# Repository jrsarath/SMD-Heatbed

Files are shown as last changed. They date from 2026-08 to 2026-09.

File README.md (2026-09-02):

# Tejasvini (तेजस्विनी) — Open-Source Heatplate Controller






**Tejasvini** is an open-source, precision heatplate controller firmware engineered for surface-mount (SMD/SMT) reflow soldering, PCB pre-heating, and rework. It runs on the **Raspberry Pi Pico (RP2040)** paired with an **Elecrow 4.3" Pico DVI Display** running a high-resolution native LVGL user interface with touchscreen and rotary encoder controls.

---

## Key Features

* **Dual NTC Thermistor Sensing**: Redundant 100K 3950 NTC thermistors with 32x oversampling, trimmed-mean outlier rejection, and real-time sensor divergence detection.
* **AC Zero-Cross SSR Drive**: 1000ms time-proportioning slow PWM tailored specifically for AC zero-crossing Solid State Relays (e.g. Fotek SSR-25DA) to avoid half-cycle jitter.
* **Soft-Start Reference Ramping**: Temperature ramps smoothly towards setpoint at $1.5^\circ\text{C}/\text{s}$ to prevent thermal shock to ceramic SMD components and eliminate overshoot.
* **Automated 4-Stage Reflow State Machine**:
  * **Lead-Free (SAC305)**: 245°C peak reflow curve.
  * **Leaded (Sn63Pb37)**: 215°C peak reflow curve.
  * **Low-Temperature (Sn42Bi58)**: 150°C peak reflow curve for heat-sensitive components and plastic connectors.
  * **Manual Mode**: Direct setpoint adjustment (0°C to 270°C).
* **High-Resolution PicoDVI Dashboard**: Renders a 240x400 portrait UI (400x240 hardware DVI upscaled 2x to 800x480) with real-time temperature dials, duty percentage, stage timer, and status.
* **Dual Input Interfaces**: Capacitive touchscreen (GT911) with full on-screen control + detented rotary encoder and debounced push-button.
* **Comprehensive Safety Interlocks**: Fast-trip open/short circuit detection (<100ms), thermal runaway monitoring, 280°C emergency shutdown, pre-heat sensor discrepancy check, and clamped duty cycle (max 40%).
* **Real-Time Telemetry**: Tagged structured telemetry streamed simultaneously over USB CDC Serial and UART `Serial1` (115200 baud).

---

## Hardware Specifications & Bill of Materials (BOM)

| Component | Specification / Recommendation | Purpose |
| :--- | :--- | :--- |
| **Microcontroller** | Raspberry Pi Pico (RP2040, 133MHz, 264KB SRAM, 2MB Flash) | Main controller |
| **Display Module** | Elecrow CrowPanel 4.3" Pico DVI Display (RTD2281 scaler, 800x480 panel) | Native DVI output & touch |
| **Touch Controller**| Goodix GT911 Capacitive Touchscreen (I2C) | On-screen user input |
| **Rotary Encoder** | EC11 detented incremental quadrature encoder with momentary push-button | Manual dial input |
| **Heating Element** | 400W 220V/110V PTC Aluminum Heatplate (e.g. 100mm $\times$ 100mm) | Soldering hot plate |
| **Solid State Relay**| 3.3V Logic-compatible Zero-Cross AC SSR (e.g. Fotek SSR-25DA, 25A 250VAC) | Heater power switching |
| **Temperature Sensors**| $2\times$ 100kΩ NTC Thermistors (Beta = 3950, glass bead cartridge) | Redundant thermal sensing |
| **Divider Resistors**| $2\times$ 100kΩ 1% 1/4W Metal Film Resistors | Precision ADC voltage dividers |
| **Thermal Fuse (TCO)**| Non-resettable thermal cut-off fuse rated at 260°C to 280°C | Physical over-temp safety |
| **Mains Fuse** | 3.15A (for 230V) or 5A (for 110V) fast-acting fuse in IEC inlet socket | Mains over-current safety |

---

## Hardware Pinout Configuration

The firmware assigns GPIO pins in [`src/config.h`](src/config.h) as follows:

```
                                  Raspberry Pi Pico
                                     +---+--+---+
                       (TX) GPIO 0  -| 1    40 |-  VBUS (5V Input)
                       (RX) GPIO 1  -| 2    39 |-  VSYS
              (Encoder A)   GPIO 2  -| 4    38 |-  GND
              (Encoder B)   GPIO 3  -| 5    37 |-  3V3_EN
                            ...     -| ...  36 |-  3V3(OUT)
              (Touch SDA)   GPIO 20 -| 26   34 |-  GPIO 28 (Encoder Button)
              (Touch SCL)   GPIO 21 -| 27   32 |-  GPIO 27 (ADC1 / NTC2)
              (SSR Drive)   GPIO 22 -| 29   31 |-  GPIO 26 (ADC0 / NTC1)
              (Backlight)   GPIO 24 -| 30   30 |-  RUN
              (Touch INT)   GPIO 25 -| 31   29 |-  GPIO 29 (Touch RST)
                                     +----------+
```

| Signal | GPIO Pin | Hardware Function | Notes |
| :--- | :--- | :--- | :--- |
| `PIN_ENA` | GPIO 2 | Rotary Encoder Phase A | Internal pullup enabled |
| `PIN_ENB` | GPIO 3 | Rotary Encoder Phase B | Internal pullup enabled |
| `PIN_EBT` | GPIO 28 | Rotary Encoder Push-Button | Internal pullup enabled (Active LOW) |
| `PIN_SSR` | GPIO 22 | Solid State Relay Output | 3.3V logic time-proportioning drive |
| `PIN_NTC1` | GPIO 26 | Primary NTC Thermistor | RP2040 ADC0 (12-bit), 100kΩ divider |
| `PIN_NTC2` | GPIO 27 | Secondary NTC Thermistor | RP2040 ADC1 (12-bit), 100kΩ divider |
| `PIN_BACKLIGHT` | GPIO 24 | Display Backlight Enable | Active LOW |
| `TOUCH_SDA` | GPIO 20 | GT911 I2C Data | 4.7kΩ pullups required |
| `TOUCH_SCL` | GPIO 21 | GT911 I2C Clock | 4.7kΩ pullups required |
| `TOUCH_INT` | GPIO 25 | GT911 Touch Interrupt | Configured in `src/touch.h` |
| `TOUCH_RST` | GPIO 29 | GT911 Touch Reset | Configured in `src/touch.h` |
| `SERIAL_TX` | GPIO 0 | Telemetry UART TX (`Serial1`) | 115200 baud |
| `SERIAL_RX` | GPIO 1 | Telemetry UART RX (`Serial1`) | 115200 baud |

---

## Enclosure & 3D Hardware Models

Tejasvini includes CAD & 3D models in [`assets/3d files/`](assets/3d%20files/) for building a complete desktop workstation enclosure:

### 3D Printable Enclosure Parts
| Model File | Part Description | Recommended Material | Print Settings |
| :--- | :--- | :--- | :--- |
| [`Frame - Main.stl`](assets/3d%20files/Frame%20-%20Main.stl) | Main chassis housing RP2040, SSR, power supply & wiring | PETG / ABS / ASA | 35% Infill, 4 walls |
| [`Frame - Display.stl`](assets/3d%20files/Frame%20-%20Display.stl) | Front bezel securing the 4.3" Pico DVI display & GT911 touch | PETG / ABS / PLA | 25% Infill, 3 walls |
| [`Display Bottom Plate.stl`](assets/3d%20files/Display%20Bottom%20Plate.stl) | Rear protective backing plate for the display module | PETG / ABS / PLA | 25% Infill, 3 walls |
| [`Top Plate.stl`](assets/3d%20files/Top%20Plate.stl) | Top deck plate surrounding the heatplate surface | **ABS / ASA / PC** *(High HDT)* | 40% Infill, 4 walls |

### Physical Hardware Reference (Do NOT 3D Print)
| Model File | Part Description | Material | Notes |
| :--- | :--- | :--- | :--- |
| [`Heating Plate.stl`](assets/3d%20files/Heating%20Plate.stl) | **Heatplate CAD Reference** | **Aluminium** | **Visualization & fit checks only.** Must be fabricated from aluminum (sheet / CNC machined block). Do **not** 3D print this part. |

> [!IMPORTANT]
> **Thermal Standoffs & Material Selection**:
> * **Heating Plate Material**: The heating surface (`Heating Plate.stl`) MUST be made of **aluminium** to conduct heat and withstand reflow temperatures up to 250°C.
> * **Enclosure Plastic**: For printed components near the heatplate (`Top Plate.stl`), use materials with a high Heat Deflection Temperature (HDT) such as **ABS, ASA, or Polycarbonate (PC)**. Standard PLA softens around 55°C–60°C and must **not** be used near the heater. Always install silicone washers, ceramic washers, or brass/PTFE standoffs to thermally isolate the 200°C+ aluminum plate from printed enclosure surfaces.

---

## Safety Architecture & Physical Protections

> [!CAUTION]
> **Mains Voltage & Thermal Fire Warning**:
> Heating elements can exceed 280°C and cause severe burns, fire, or toxic gas generation. Solid-state relays almost always fail in a **shorted (ON)** state.
>
> You MUST install independent physical hardware protections:
> 1. **Thermal Cut-Off Fuse (TCO)**: A physical bimetallic or chemical thermal fuse rated at 260°C–280°C MUST be clamped directly against the aluminum plate in series with the AC Live wire.
> 2. **Chassis Earth Grounding**: The metal heatplate MUST be bonded to the AC mains protective earth wire (<0.1Ω to plug ground pin).
> 3. **Mains Fuse**: Fast-acting fuse sized for plate wattage.
>
> See [docs/hardware_and_safety.md](docs/hardware_and_safety.md) for full schematics and electrical requirements.

### Firmware Multi-Tier Safety Checks
* **Instant Open/Short Detection (<100ms)**: Raw ADC counts outside 50 to 4050 counts or raw temperatures outside -20°C to 300°C trip an immediate emergency shutdown.
* **Thermal Runaway Monitor**: Detects disconnected sensors or insufficient temperature rise under active heating within 18 seconds (`SAFETY_PERIOD`).
* **Sensor Divergence Lockout**: Detects detached sensors or uneven plate heating if the dual thermistors disagree by $> 35^\circ\text{C}$ during heating, or $> 15^\circ\text{C}$ before startup.
* **Duty Cycle Clamping**: SSR output is hard-clamped to 40% (`MAX_DUTY`) to protect the heating element and SSR.
* **Latching Shutdown (`trigger_safety_shutdown`)**: All safety trips immediately force the SSR GPIO LOW and require explicit user intervention to clear.

---

## Firmware Software Architecture

The firmware is structured into modular components operating cooperatively:

```text
Tejasvini/
├── Tejasvini.ino             # Main Arduino sketch (setup & cooperative non-blocking loop)
├── CMakeLists.txt            # CMake build definition
├── LICENSE                   # MIT License
├── README.md                 # Project documentation (this file)
├── CONTRIBUTING.md           # Developer guidelines & safety standards
├── CODE_OF_CONDUCT.md        # Contributor Covenant Code of Conduct
├── assets/
│   └── 3d files/             # Ready-to-print STL enclosure & mounting models
├── docs/
│   ├── architecture.md       # Detailed software architecture & state machines
│   ├── hardware_and_safety.md# Pinout, NTC voltage divider math, SSR & safety fuses
│   └── calibration_and_tuning.md # PI loop tuning & sensor calibration
└── src/
    ├── config.h              # Hardware pinout, thermal constants & safety parameters
    ├── display_manager.h/.cpp# PicoDVI display driver, LVGL bridge, reflow state machine
    ├── input_handler.h/.cpp  # Rotary encoder decoding & button debouncing
    ├── telemetry.h/.cpp      # USB CDC & UART serial logging
    ├── thermal_control.h/.cpp# Dual NTC ADC acquisition, PI regulator, SSR PWM, safety
    ├── touch.h/.cpp          # Touchscreen driver abstraction (GT911)
    └── ui/                   # EEZ Studio generated LVGL UI screens, styles, and vars
```

---

## Building and Flashing the Firmware

### Option 1: Using `arduino-cli` (Recommended)

1. Install the [Earle F. Philhower RP2040 Core](https://github.com/earlephilhower/arduino-pico).
2. Install required Arduino libraries (`PicoDVI`, `Adafruit_GFX`, `Adafruit_BusIO`, `lvgl`, `RP2040_PWM`, `RPI_PICO_TimerInterrupt`, `TAMC_GT911`).
3. Compile the project:
   ```bash
   arduino-cli compile \
     -b rp2040:rp2040:rpipico \
     --build-property "build.extra_flags=-DLV_LVGL_H_INCLUDE_SIMPLE -DLV_USE_OBJ_NAME=1 -DLV_USE_TRANSLATION=1 -Wall -Wextra" \
     .
   ```
4. Flash to the board:
   ```bash
   arduino-cli upload -p /dev/tty.usbmodem* -b rp2040:rp2040:rpipico .
   ```
   *(Or hold the **BOOTSEL** button on the Pico while plugging in USB, then copy the compiled `.uf2` file to the `RPI-RP2` drive).*

### Option 2: Using the Arduino IDE 2.x

1. Open `Tejasvini.ino` in Arduino IDE.
2. Select **Board:** `Raspberry Pi Pico` (under Raspberry Pi RP2040 by Earle Philhower).
3. Under **Tools**, configure:
   * **CPU Speed:** 133 MHz (or 200 MHz)
   * **Flash Size:** 2MB (Sketch: 1984KB, FS: 64KB)
   * **USB Stack:** Adafruit TinyUSB
4. Click **Verify** (`Ctrl+R` / `Cmd+R`) and **Upload** (`Ctrl+U` / `Cmd+U`).

---

## Operating Instructions

1. **Boot Screen**: Displays the project banner, firmware version, and initializes the DVI dashboard.
2. **Temperature Adjustment**:
   * Rotate the rotary encoder dial to increase/decrease target temperature in 1°C steps.
   * Or tap the on-screen temperature arc/buttons to adjust setpoint.
3. **Toggle Heating**:
   * Short-press the encoder knob or tap the **START HEATING** button on the display.
4. **Reflow Profile Selection**:
   * Tap the profile dropdown on the dashboard to select **MANUAL**, **LEAD FREE**, **LEADED**, or **LOW TEMP**.
   * Progress bar indicates current stage progress (0–25% Preheat, 25–50% Soak, 50–75% Reflow Peak, 75–100% Cool).
5. **Clear Error / Reset Fault**:
   * Long-press the encoder knob (>1.0 second) to attempt clearing an error state once sensor readings return to valid bounds.

---

## Telemetry Stream

Tejasvini streams structured status logs every 1000ms over USB Serial and UART `Serial1` (GPIO 0 TX / GPIO 1 RX @ 115200 baud):

```text
[Telemetry] Temp: 149.8C (T1: 150.1, T2: 149.5, dT: 0.6) | Target: 150C (Ref: 150.0) | Duty: 24.5% | Status: SOAK [LEAD FREE] | ADC: [2480/98.4k, 2475/98.1k] | Heap: 87450B
```

Send `b` or `?` over the serial monitor to reprint the diagnostic boot banner.

---

## Documentation

* [Architecture & State Machines](docs/architecture.md)
* [Hardware Wiring, Schematics & Safety Fuses](docs/hardware_and_safety.md)
* [Calibration & Controller Tuning](docs/calibration_and_tuning.md)

---

## Contributing

Contributions are welcome! Please read [CONTRIBUTING.md](CONTRIBUTING.md) and our [Code of Conduct](CODE_OF_CONDUCT.md) before submitting pull requests.

---

## License

This project is open-source under the **MIT License**. See the [LICENSE](LICENSE) file for details.

Copyright (c) 2026 Sarath "Delta" Singh <br />
Made with ❤️ in Kolkata, India.

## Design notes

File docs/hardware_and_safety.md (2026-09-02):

# Hardware Wiring & Physical Safety Guide

This document outlines the electrical connections, sensor circuits, solid-state relay considerations, and mandatory physical safety mechanisms required for building and operating **Tejasvini**.

---

## 1. Safety Warnings & Physical Protections

> [!CAUTION]
> **DANGER: MAINS VOLTAGE AND HIGH TEMPERATURE HAZARDS**
> * Tejasvini controls **mains AC voltage** (110V / 230V AC) and heating elements capable of reaching **exceeding 280°C**.
> * Mains electricity can cause fatal electric shock. High temperatures cause severe burns and fire.
> * **Software is NOT a safety mechanism.** Solid-state relays fail in a short-circuit (ON) state in roughly 90% of failure modes. If a microcontroller crashes or an SSR semiconductor fails shorted, firmware cannot shut off power.
> * You MUST incorporate the physical hardware protections described below.

### Mandatory Physical Protections
1. **Thermal Cut-Off Fuse (TCO / Thermal Fuse)**:
   - Install a non-resettable thermal fuse (rated at **260°C to 280°C**) clamped directly to the underside of the aluminum heatplate in physical contact with the metal.
   - Wire the thermal fuse in **series** with the AC Live line feeding the heating element. If the plate overheats for any reason, the fuse physically melts and permanently breaks the circuit.
2. **Protective Earth (PE) Grounding**:
   - The aluminum heatplate and all exposed metal chassis parts MUST be securely bonded to the AC mains Earth wire with a dedicated screw, lock washer, and ring terminal.
   - Use a multimeter to verify $< 0.1\,\Omega$ resistance between the heatplate surface and the ground pin of the mains plug.
3. **Mains Over-Current Fuse**:
   - Install a properly rated fast-blow fuse in a fused AC inlet socket (e.g., 3.15A for 230V 400W plate, or 5A for 110V 400W plate).
4. **Solid-State Relay (SSR) Heatsinking**:
   - Solid-state relays exhibit an internal forward voltage drop of $\approx 1.2\,\text{V}$ to $1.6\,\text{V}$. At a 2A load, this dissipates $2.5\,\text{W}$ to $3.5\,\text{W}$ of heat inside the SSR.
   - Mount the SSR to a metal chassis or aluminum heatsink using thermal paste. Never operate the SSR in a sealed unventilated plastic enclosure.

---

## 2. Hardware Pinout Table

| Signal | RP2040 GPIO Pin | Hardware Header / Function | Notes |
| :--- | :--- | :--- | :--- |
| `PIN_ENA` | GPIO 2 | Rotary Encoder Phase A | Internal `INPUT_PULLUP` enabled |
| `PIN_ENB` | GPIO 3 | Rotary Encoder Phase B | Internal `INPUT_PULLUP` enabled |
| `PIN_EBT` | GPIO 28 | Rotary Encoder Push-Button | Internal `INPUT_PULLUP` enabled (Active LOW) |
| `PIN_SSR` | GPIO 22 | Solid State Relay Output | 3.3V Logic Drive (Time-Proportioning) |
| `PIN_NTC1` | GPIO 26 | Primary Thermistor (ADC0) | 12-bit ADC, 100kΩ divider to GND |
| `PIN_NTC2` | GPIO 27 | Secondary Thermistor (ADC1) | 12-bit ADC, 100kΩ divider to GND |
| `PIN_BACKLIGHT`| GPIO 24 | Display Backlight Control | Active LOW (driven LOW to illuminate) |
| `TOUCH_SDA` | GPIO 20 | GT911 Touch Controller I2C SDA | Requires 4.7kΩ pullups to 3.3V |
| `TOUCH_SCL` | GPIO 21 | GT911 Touch Controller I2C SCL | Requires 4.7kΩ pullups to 3.3V |
| `TOUCH_INT` | GPIO 25 | GT911 Touch Controller Interrupt | Configured in `src/touch.h` |
| `TOUCH_RST` | GPIO 29 | GT911 Touch Controller Reset | Configured in `src/touch.h` |
| `SERIAL_TX` | GPIO 0 | Telemetry UART TX (`Serial1`) | 115200 baud, 8N1 |
| `SERIAL_RX` | GPIO 1 | Telemetry UART RX (`Serial1`) | 115200 baud, 8N1 |

---

## 3. Dual NTC Thermistor Circuit & Math

Tejasvini uses **dual 100K 3950 NTC thermistors** mounted at separate positions across the heating surface (e.g. center and edge) to provide redundancy and detect thermal gradients or detached sensors.

### 3.1 Voltage Divider Circuit
Each thermistor is wired in a high-side divider configuration:

```text
       3.3V (VCC)
         │
       ┌─┴─┐
       │   │  NTC Thermistor (100kΩ @ 25°C)
       │   │  R_NTC
       └─┬─┘
         ├──────────────> RP2040 ADC Pin (GPIO 26 or GPIO 27)
       ┌─┴─┐
       │   │  Precision Divider Resistor (100kΩ, 1% tolerance)
       │   │  R_DIVIDER
       └─┬─┘
         │
        GND
```

### 3.2 Mathematical Derivation
The voltage at the ADC input pin is:
$$V_{\text{out}} = V_{\text{cc}} \cdot \frac{R_{\text{divider}}}{R_{\text{ntc}} + R_{\text{divider}}}$$

With a 12-bit ADC full-scale count of $4095$ corresponding to $V_{\text{cc}}$:
$$\frac{\text{ADC}}{4095} = \frac{R_{\text{divider}}}{R_{\text{ntc}} + R_{\text{divider}}}$$

Inverting both sides:
$$\frac{4095}{\text{ADC}} = \frac{R_{\text{ntc}}}{R_{\text{divider}}} + 1 \implies R_{\text{ntc}} = R_{\text{divider}} \cdot \left(\frac{4095}{\text{ADC}} - 1\right)$$

### 3.3 Steinhart-Hart / Beta Temperature Conversion
From the calculated resistance $R_{\text{ntc}}$, temperature in Kelvin is determined via the Beta equation:
$$\frac{1}{T} = \frac{1}{T_0} + \frac{1}{\beta} \cdot \ln\left(\frac{R_{\text{ntc}}}{R_0}\right)$$

Where:
* $T_0 = 298.15\,\text{K}$ ($25^\circ\text{C}$)
* $R_0 = 100{,}000\,\Omega$ ($100\text{k}\Omega$)
* $\beta = 3950\,\text{K}$
* $T_{\text{Celsius}} = T_{\text{Kelvin}} - 273.15$

### 3.4 Electrical Fault Signatures
* **Broken / Disconnected NTC (Open Circuit)**: $R_{\text{ntc}} \to \infty$. The ADC pin is pulled to GND by $R_{\text{divider}}$, reading $\text{ADC} \approx 0$ counts.
* **Shorted NTC (Short to 3.3V)**: $R_{\text{ntc}} \to 0$. The ADC pin is pulled directly to 3.3V, reading $\text{ADC} \approx 4095$ counts.
* **Firmware Fast Bounds**: Tejasvini checks $\text{ADC} < 50$ or $\text{ADC} > 4050$ counts and shuts off immediately ($<100\text{ms}$).

---

## 4. Solid-State Relay (SSR) Wiring

### 4.1 AC Mains SSR Connection
Connect a 3.3V-logic compatible AC Zero-Cross Solid State Relay (e.g. Fotek SSR-25DA or Crydom D2425):

```text
[Raspberry Pi Pico]                      [AC Mains Solid-State Relay]
GPIO 22 ───────────────────────────────> Input (+) [Terminal 3]
GND     ───────────────────────────────> Input (-) [Terminal 4]

[AC Mains 230V/110V Live] ────[Mains Fuse]───[Thermal Cutoff 260°C]───> Output [Terminal 1]
                                                                        Output [Terminal 2] ───> [PTC Heatplate L]
[AC Mains Neutral] ────────────────────────────────────────────────────────────────────────────> [PTC Heatplate N]
[AC Mains Earth]   ────────────────────────────────────────────────────────────────────────────> [Heatplate Metal Body]
```

### 4.2 Why Time-Proportioning is Used Instead of High-Frequency PWM
Zero-crossing AC solid-state relays only switch on and off when the AC line voltage passes through 0V (every 10ms at 50Hz, or 8.33ms at 60Hz).
* Applying a 1000 Hz PWM signal to an AC zero-cross SSR results in random, irregular half-cycle conduction, extreme flicker, and unpredictable power delivery.
* Tejasvini uses **Time-Proportioning PWM** over a 1000ms window (`SSR_WINDOW_MS 1000`). At 25% duty, the relay conducts for 250ms (12.5 complete AC cycles at 50Hz) and remains OFF for 750ms.

---

## 5. Mechanical Enclosure & 3D Hardware Models

CAD & 3D models for Tejasvini are located in [`assets/3d files/`](../assets/3d%20files/).

### 5.1 3D Model Manifest

#### 3D Printable Parts
| File Name | Functional Description | Print Recommendation |
| :--- | :--- | :--- |
| [`Frame - Main.stl`](../assets/3d%20files/Frame%20-%20Main.stl) | Main structural chassis. Houses the Raspberry Pi Pico, solid-state relay, AC terminal block, and power distribution. | PETG / ABS / ASA, 35% infill, 4 perimeters |
| [`Frame - Display.stl`](../assets/3d%20files/Frame%20-%20Display.stl) | Angled front display bezel. Secures the Elecrow 4.3" CrowPanel RTD2281 DVI screen and GT911 touch panel. | PETG / ABS / PLA, 25% infill, 3 perimeters |
| [`Display Bottom Plate.stl`](../assets/3d%20files/Display%20Bottom%20Plate.stl) | Rear/bottom cover plate for the display module housing, protecting display PCB and encoder wiring. | PETG / ABS / PLA, 25% infill, 3 perimeters |
| [`Top Plate.stl`](../assets/3d%20files/Top%20Plate.stl) | Top cosmetic deck plate surrounding the heating zone, providing a smooth, flush exterior interface. | **ABS / ASA / PC**, 40% infill, 4 perimeters |

#### Physical Hardware Reference (Do NOT 3D Print)
| File Name | Functional Description | Material | Notes |
| :--- | :--- | :--- | :--- |
| [`Heating Plate.stl`](../assets/3d%20files/Heating%20Plate.stl) | Physical heating plate reference model. | **Aluminium** | **Visualization only.** Must be fabricated from aluminum (sheet / CNC machined plate). Never 3D print. |

### 5.2 Assembly & Thermal Isolation
Because the aluminum heatplate operates at temperatures up to 250°C, direct contact between the metal plate and thermoplastic components will cause warping or melting:

1. **Aluminium Plate Construction**:
   - The actual heating surface represented by `Heating Plate.stl` **must be made of aluminum** for optimal thermal conductivity and heat distribution across the PCB work area.
2. **Thermal Standoffs**:
   - Mount the aluminum heating plate to the chassis using M3 brass standoffs (minimum 10mm to 15mm height) to establish a convective air gap above the electronics.
   - Place heat-resistant silicone grommets or ceramic washers between the screw heads and the plate mounting holes to prevent conductive heat transfer into the printed `Top Plate.stl` or chassis.
3. **Thermal Fuse Mounting**:
   - The 260°C–280°C thermal cut-off fuse (TCO) should be mounted directly to the underside of the aluminum heatplate with a metal retaining clip or high-temperature silicone adhesive, ensuring intimate thermal contact.
4. **Internal Airflow**:
   - The main frame features ventilation slots to promote natural convection around the SSR heatsink and the Raspberry Pi Pico.

### 5.3 Filament Material Guide

| Filament Material | Glass Transition ($T_g$) | Heat Deflection (HDT @ 0.45MPa) | Suitability for Tejasvini |
| :--- | :--- | :--- | :--- |
| **PLA** | ~55°C – 60°C | ~55°C | **Only for Display Bezel**. Never use near the heater plate. |
| **PETG** | ~80°C – 85°C | ~70°C – 75°C | Excellent for Main Frame & Display housing. |
| **ABS / ASA** | ~105°C | ~95°C – 100°C | **Recommended** for Heating Plate mount and Top Plate. |
| **PC (Polycarbonate)** | ~145°C – 150°C | ~135°C – 140°C | **Best performance** for high-temperature continuous operation. |

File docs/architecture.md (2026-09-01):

# Tejasvini Firmware Architecture

This document provides a comprehensive technical overview of the software architecture, subsystem interactions, control loops, and memory organization of the **Tejasvini** heatplate controller firmware.

---

## 1. System Overview & Execution Model

Tejasvini runs on a **Raspberry Pi Pico (RP2040)** with dual ARM Cortex-M0+ cores. The current firmware executes on **Core 0** in a cooperative, non-blocking polling model inside `loop()`, ensuring predictable timing, low latency, and deterministic memory behavior without complex inter-core synchronization.

```mermaid
graph TD
    A[Tejasvini.ino loop] --> B[input_handler_update]
    A --> C[thermal_control_update]
    A --> D[display_manager_update]
    A --> E[telemetry_update]
    A --> F[yield]

    B --> B1[Rotary Encoder Quadrature Decoding]
    B --> B2[Button Debounce Short/Long Press]

    C --> C1[read_oversampled_adc 32x Trimmed]
    C --> C2[Raw ADC & Temp Bounds Check]
    C --> C3[EMA Low-Pass & Slew Limiter]
    C --> C4[PI Controller & Soft-Start Ramp]
    C --> C5[update_ssr_actuation Time-Proportioning]
    C --> C6[Thermal Runaway & Divergence Checks]

    D --> D1[update_profile_and_progress State Machine]
    D --> D2[ui_tick EEZ Studio]
    D --> D3[lv_timer_handler LVGL Renderer]
    D --> D4[dvi_flush_cb PicoDVI Draw]

    E --> E1[Serial USB CDC & Serial1 UART 115200]
```

### Main Execution Loop Breakdown
| Function | Frequency / Interval | Purpose |
| :--- | :--- | :--- |
| `input_handler_update()` | Continuous (~100-200 Hz) | Instant quadrature edge detection and button debouncing |
| `thermal_control_update()` | SSR: Continuous<br>PI Loop: 10 Hz (100 ms) | Time-proportioning SSR actuation and 100ms PI temperature regulation |
| `display_manager_update()` | Continuous (~30-60 Hz) | LVGL tick handling, UI animations, reflow state transitions, DVI flush |
| `telemetry_update()` | 1 Hz (1000 ms) | Formatted telemetry output over USB Serial and Hardware UART |

---

## 2. Thermal Control & Safety Subsystem (`src/thermal_control`)

### 2.1 Sensor Acquisition Pipeline
Dual 100K NTC thermistors (`PIN_NTC1` on ADC0/GPIO 26, `PIN_NTC2` on ADC1/GPIO 27) are read through a 3-tier filtering pipeline:

1. **32x Oversampling with Outlier Rejection (`read_oversampled_adc`)**:
   - 32 analog samples acquired with 4µs settling delays.
   - Sorted in-place using an insertion sort on a small stack buffer.
   - The 6 highest and 6 lowest readings are discarded (trimmed mean).
   - The 20 middle samples are averaged, eliminating power rail switching spikes, DVI noise, and ADC glitch pulses.
2. **Fast Raw ADC & Electrical Bounds Check**:
   - Raw ADC values must lie strictly between `ADC_MIN_VALID_COUNTS` (50) and `ADC_MAX_VALID_COUNTS` (4050).
   - Raw temperatures must lie strictly between `NTC_MIN_VALID_TEMP` (-20°C) and `NTC_MAX_VALID_TEMP` (300°C).
   - If either sensor violates these bounds (broken wire, loose plug, or dead short), `trigger_safety_shutdown()` trips **immediately** ($< 100\text{ms}$) without passing the corrupt value to the smoothing filter.
3. **EMA Low-Pass Filter + Physical Slew Limiter**:
   - Exponential Moving Average ($\alpha = 0.08$) smooths sensor noise.
   - A physical slew limiter clamps the maximum allowable temperature change to `0.25°C` per 100ms step (equivalent to $2.5^\circ\text{C}/\text{s}$ max rise/fall).

### 2.2 PI Regulation & Soft-Start Ramping
* **Soft-Start Ramping**: Rather than stepping the PI setpoint directly to the target temperature, `reference_temp` ramps towards `set_temp` at a rate of `RAMP_RATE_DEG_PER_SEC` ($1.5^\circ\text{C}/\text{s}$). This prevents severe thermal shock to delicate ceramic SMD components and reduces heater overshoot.
* **PI Controller**:
  $$e(t) = T_{\text{ref}}(t) - T_{\text{measured}}(t)$$
  $$u(t) = K_p \cdot e(t) + K_i \cdot \int e(t)\,dt$$
  - $K_p = 1.5$, $K_i = 0.02$.
  - Integration accumulator is time-scaled ($dt$ integration) and includes **anti-windup clamping**: accumulator growth is frozen when the output saturates at `MAX_DUTY` (40%) or `MIN_DUTY` (0%).

### 2.3 SSR Actuation: Time Proportioning
Because AC Solid State Relays (such as the Fotek SSR-25DA) switch on AC zero-crossings (every 10ms for 50Hz or 8.33ms for 60Hz), standard high-frequency PWM cannot be used.
Tejasvini uses **Time-Proportioning Slow PWM** (`SSR_TIME_PROPORTIONING 1`):
* A 1000ms cycle window (`SSR_WINDOW_MS 1000`) is established.
* At 40% duty, the SSR pin is driven HIGH for 400ms and LOW for 600ms.
* `update_ssr_actuation()` is evaluated continuously on every loop pass for sub-millisecond switching accuracy.

### 2.4 Multi-Layered Safety Interlocks
1. **Emergency Over-Temperature Shutdown**: If composite or individual sensor temperature exceeds `OVERTEMP_SHUTDOWN` (280°C), the SSR is instantly killed and locked out.
2. **Sensor Divergence Lockout**:
   - **Pre-Heat**: Both sensors must agree within `MAX_STARTUP_NTC_DIFF` (15°C) before heating is permitted to start.
   - **Active Heating**: If sensors diverge by $> 35^\circ\text{C}$ (`MAX_NTC_DIFF`) for 5 consecutive cycles (500ms debounce), the heater is shut down.
3. **Thermal Runaway Monitor**:
   - When driving $\ge 20\%$ duty with a deficit $> 10^\circ\text{C}$, temperature must rise by at least `SAFETY_THRESHOLD` (2.0°C) within `SAFETY_PERIOD` (18 seconds).
   - Hysteresis prevents timer starvation under fluctuating power.
4. **Centralized Fail-Safe Shutdown (`trigger_safety_shutdown`)**:
   - Latches `error_state = true`.
   - Forces `heater = false`, `duty = 0.0f`, `acc = 0.0f`.
   - Directly writes `PIN_SSR` LOW.
   - Requires explicit user interaction to reset.

---

## 3. Display & UI Subsystem (`src/display_manager` & `src/ui`)

### 3.1 Display Pipeline (PicoDVI & LVGL 8.3.x)
* **Hardware Output**: PicoDVI generates a 400x240 RGB565 DVI signal at 60Hz. The Elecrow CrowPanel RTD2281 scaler board upscales this 2x to fill the 800x480 native LCD panel.
* **Rotation**: The display is rotated 270° (`setRotation(3)`), presenting a logical **240x400 Portrait** UI to LVGL.
* **Partial Buffer Strategy**: LVGL renders into an 8-line partial buffer (`240 * 8 * 2 = 3840 bytes`), consuming negligible SRAM while providing artifact-free rendering.
* **Touch Controller**: Bridges GT911 capacitive touch over I2C (GPIO 20 SDA, GPIO 21 SCL), converting touch coordinates to 240x400 portrait space.

### 3.2 Reflow Profile State Machine
`display_manager.cpp` manages an automated 4-stage reflow state machine:

```mermaid
stateDiagram-v2
    [*] --> STAGE_IDLE
    STAGE_IDLE --> STAGE_PREHEAT : Start Heating (Profile != MANUAL)
    STAGE_IDLE --> MANUAL_HEATING : Start Heating (Profile == MANUAL)

    STAGE_PREHEAT --> STAGE_SOAK : Reached preheat_temp
    STAGE_SOAK --> STAGE_REFLOW : soak_time_s elapsed
    STAGE_REFLOW --> STAGE_COOL : peak_dwell_s elapsed (Heater OFF)
    STAGE_COOL --> STAGE_IDLE : Cooled <= cool_temp (50°C)

    STAGE_PREHEAT --> STAGE_IDLE : User Abort / Error
    STAGE_SOAK --> STAGE_IDLE : User Abort / Error
    STAGE_REFLOW --> STAGE_IDLE : User Abort / Error
    STAGE_COOL --> STAGE_IDLE : User Cancel
    MANUAL_HEATING --> STAGE_IDLE : Stop Heating / Error
```

Supported profiles:
1. **MANUAL**: Direct setpoint control (0 - 270°C).
2. **LEAD FREE (SAC305)**: Preheat 150°C (90s) $\to$ Soak 175°C (60s) $\to$ Peak Reflow 245°C (30s dwell) $\to$ Cool to 50°C.
3. **LEADED (Sn63Pb37)**: Preheat 130°C (80s) $\to$ Soak 155°C (60s) $\to$ Peak Reflow 215°C (30s dwell) $\to$ Cool to 50°C.
4. **LOW TEMP (Sn42Bi58)**: Preheat 90°C (60s) $\to$ Soak 115°C (45s) $\to$ Peak Reflow 150°C (25s dwell) $\to$ Cool to 45°C.

---

## 4. Memory Footprint & Resource Budget

The RP2040 features 264 KB on-chip SRAM:

| Memory Region | Allocation | Notes |
| :--- | :--- | :--- |
| **PicoDVI Framebuffer** | ~153.6 KB | Contiguously allocated in dynamic heap by `DVIGFX16` |
| **Static Data (.data + .bss)** | ~20.2 KB | Global state, buffers, LVGL static tables |
| **LVGL Draw Buffer** | 3.84 KB | 8 lines $\times$ 240 pixels $\times$ 2 bytes (RGB565) |
| **Remaining Free Heap & Stack**| >85 KB | Available for LVGL dynamic objects and call stack |
| **Flash Usage** | ~366 KB / 2 MB (17%)| Ample space for additional profiles, fonts, and assets |

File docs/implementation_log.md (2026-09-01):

# SMD-Heatbed Display Manager & LVGL Integration Log

This document serves as a persistent step-by-step implementation log to track code changes, hardware diagnostic results, memory benchmarks, state analysis, and rollback checkpoints for the PicoDVI display driver & LVGL Pro UI integration on RP2040.

---

## Current System State Analysis (Checkpoint 0)
- **Hardware Target:** Raspberry Pi Pico (RP2040) + Elecrow 4.3" Pico DVI Display (320x240 RGB565).
- **Display Hardware Driver:** `DVIGFX16 display(DVI_RES_320x240p60, picodvi_dvi_cfg)` via Adafruit PicoDVI library.
- **Current Codebase State:**
  - `src/display_manager.h` & `src/display_manager.cpp`: Bare minimum hardware driver setup with a 1-second RGB color cycle (Red -> Green -> Blue).
  - `src/config.h`: Configured with LVGL heap optimization flags (`LV_MEM_CUSTOM 1`, `LV_USE_STDLIB_MALLOC 1`, `LV_MEM_SIZE (32 * 1024U)`).
  - `SMD-Heatbed.ino`: Calls `display_manager_init()` in `setup()` and `display_manager_update()` in `loop()`.
- **Key Technical Findings:**
  - **Memory Baseline:** RP2040 SRAM is 264 KB. PicoDVI requires a 153.6 KB (153,600 bytes) contiguous dynamic allocation for the 320x240 16-bit DVI framebuffer.
  - **Prior Blocker Solved:** Default LVGL static memory pool pre-allocated ~192 KB in `.bss`, leaving only ~10 KB free heap and causing `display.begin()` to hang. Configuring dynamic heap for LVGL expanded available heap to >20 KB before DVI init and allowed `display.begin()` to report `SUCCESS`.

---

## Log Trajectory & History

### Entry #001 — Bare Minimum RGB Flashing Test
- **Date & Time:** 2026-08-25 01:23:16 IST
- **Goal:** Verify raw hardware DVI signal generation, GPIO backlight control, and DVI framebuffer writing independently of LVGL rendering pipeline.
- **Files Modified:**
  - [`src/display_manager.h`](file:///Users/jrsarath/Documents/GitHub/SMD-Heatbed/src/display_manager.h)
  - [`src/display_manager.cpp`](file:///Users/jrsarath/Documents/GitHub/SMD-Heatbed/src/display_manager.cpp)
- **Code State Details:**
  - Backlight pin `PIN_BACKLIGHT` (GPIO 24) set `OUTPUT` & `LOW`.
  - `display.begin()` called and result logged over `Serial1`.
  - `display_manager_update()` implements a 1000ms timer switching between `COLOR_RED` (`0xF800`), `COLOR_GREEN` (`0x07E0`), and `COLOR_BLUE` (`0x001F`).
- **Telemetry Log Output:**
  ```text
  [Display] Initializing backlight & PicoDVI hardware...
  [Display] Free Heap before DVI init: 20272 bytes
  [Display] Calling display.begin()...
  [Display] display.begin() result: SUCCESS
  [Display Pattern] Initial Fill: RED
  [Display Pattern] GREEN
  [Display Pattern] BLUE
  ```
- **Checkpoint Status:** BASELINE CHECKPOINT #0 CONFIRMED WORKING.

---

### Entry #002 — Integrated LVGL Pro UI Driver & Home Screen
- **Date & Time:** 2026-08-25 01:24:12 IST
- **Goal:** Re-integrate the declarative LVGL Pro UI library (`src/lvgl_ui`) onto the confirmed working PicoDVI hardware display foundation.
- **Files Modified:**
  - [`src/display_manager.h`](file:///Users/jrsarath/Documents/GitHub/SMD-Heatbed/src/display_manager.h)
  - [`src/display_manager.cpp`](file:///Users/jrsarath/Documents/GitHub/SMD-Heatbed/src/display_manager.cpp)
- **Code State Details:**
  - `lv_init()` & `lv_tick_set_cb(my_tick_cb)` initialized for hardware millisecond timing.
  - `lv_display_create(320, 240)` created with `LV_COLOR_FORMAT_RGB565` and 8-line partial buffer (`lvgl_buf`).
  - High-performance zero-copy `memcpy` row flushing to `display.getBuffer()` in `dvi_flush_cb`.
  - Registered touchscreen read callback `touch_read_cb` bridging `src/touch.h`.
  - Executed `lvgl_ui_init("")` and loaded home screen (`lv_screen_load(home_create())`).
  - Added explicit initial screen invalidation `lv_obj_invalidate(lv_screen_active())`.
  - `display_manager_update()` executes `lv_timer_handler()`.
- **Checkpoint Status:** CHECKPOINT #1 IN PROGRESS (Investigating missing flush calls).

---

### Entry #003 — Render Layer Heap Allocation Diagnostics
- **Date & Time:** 2026-08-25 01:27:37 IST
- **Observation:** `display.begin()` succeeded and firmware setup completed, but `dvi_flush_cb` was never invoked by LVGL (`0` flush calls recorded).
- **Hypothesis:** Heap memory remaining after `display.begin()` (20,272 bytes) is consumed during `lvgl_ui_init()` and `home_create()`. When `lv_timer_handler()` attempts to allocate LVGL 9 render layer buffers dynamically via `lv_malloc()`, allocation fails silently and aborts the render pass before calling `dvi_flush_cb`.
- **Files Modified:**
  - [`src/display_manager.cpp`](file:///Users/jrsarath/Documents/GitHub/SMD-Heatbed/src/display_manager.cpp)
- **Changes:**
  - Added heap measurement prints before and after `home_create()` to quantify exact RAM consumption during UI screen tree construction.
- **Checkpoint Status:** REVERTED BACK TO CHECKPOINT #0.

---

### Entry #004 — Rollback to RGB Flashing Baseline (Checkpoint #0)
- **Date & Time:** 2026-08-25 01:31:12 IST
- **Action:** User requested explicit rollback to the working RGB color flashing baseline.
- **Files Modified:**
  - [`src/display_manager.h`](file:///Users/jrsarath/Documents/GitHub/SMD-Heatbed/src/display_manager.h)
  - [`src/display_manager.cpp`](file:///Users/jrsarath/Documents/GitHub/SMD-Heatbed/src/display_manager.cpp)
- **Code State Restored:**
  - Restored bare minimum `display_manager_init()` initializing `display.begin()`, setting rotation, and filling initial RED.
  - Restored 1-second RGB flashing cycle (`display.fillScreen(COLOR_RED / GREEN / BLUE)`) in `display_manager_update()`.
  - Stripped LVGL driver calls, tick callbacks, and touch handlers from `display_manager`.
- **Checkpoint Status:** REVERTED TO BASELINE CHECKPOINT #0.

---

### Entry #005 — Key Learnings from Official LVGL Arduino Documentation
- **Date & Time:** 2026-08-25 01:51:20 IST
- **Source:** Official LVGL Arduino Integration Documentation.
- **Key Technical Insights:**
  1. **LVGL Built-in Debug Logger (`LV_USE_LOG`)**:
     - Enabling `#define LV_USE_LOG 1` and registering a custom UART print callback (`lv_log_register_print_cb(my_log_cb)`) allows LVGL to output internal warnings, heap allocation errors (`LV_LOG_LEVEL_WARN` / `LV_LOG_LEVEL_ERROR`), and render pipeline traces directly to `Serial1`.
     - This gives empirical visibility into why a render pass stutters or aborts.
  2. **Configuration Hierarchy (`lv_conf.h`)**:
     - Placement of `lv_conf.h` in Arduino libraries directory next to `lvgl`.
     - Explicit color depth configuration `<ApiLink name="LV_COLOR_DEPTH" />` (16 for RGB565).
  3. **Arduino Integration Flow (`LVGL_Arduino.ino`)**:
     - Standard custom display driver wrapper (`lv_display_create`, `lv_display_set_flush_cb`, `lv_display_set_buffers`) + touchpad registration (`lv_indev_create`, `lv_indev_set_read_cb`).
     - Periodic `lv_timer_handler()` processing inside `loop()`.
- **Action Plan Formulated:**
  - Register `lv_log_register_print_cb(my_log_cb)` to catch silent LVGL errors over `Serial1`.
  - Verify `LV_COLOR_DEPTH` (16) and color format alignment.
- **Checkpoint Status:** BASELINE CHECKPOINT #0 (Prepared for Logging-Enabled Integration).

---

### Entry #006 — LVGL Display & UI Screen Registration Architecture
- **Date & Time:** 2026-08-25 01:52:15 IST
- **Architectural Clarification:**
  - **1. Display Driver Registration (`lv_display_create`)**:
    Calling `lv_display_create(SCREEN_WIDTH, SCREEN_HEIGHT)` registers the physical display dimensions (320x240), color format (`LV_COLOR_FORMAT_RGB565`), draw buffer (`lvgl_buf`), and flush callback (`dvi_flush_cb`) with LVGL. It sets `lv_display_get_default()`.
  - **2. UI Screen Registration (`lv_screen_load`)**:
    Creating a screen via `home_create()` instantiates the top-level screen object (`lv_obj_create(NULL)`). Calling `lv_screen_load(home)` binds that screen tree to LVGL's active display.
  - **3. Hardware Bridge (`dvi_flush_cb`)**:
    LVGL renders widgets into `lvgl_buf` and passes the pixel block (`px_map`) to `dvi_flush_cb`. `dvi_flush_cb` writes those pixels into `display.getBuffer()`, where PicoDVI hardware streams them to the screen.
- **Checkpoint Status:** BASELINE CHECKPOINT #0.

---

### Entry #007 — Display & Screen Registration with LVGL Native Logger
- **Date & Time:** 2026-08-25 01:52:41 IST
- **Goal:** Re-register LVGL display driver (`lv_display_create`), touch indev (`lv_indev_create`), and UI home screen (`lv_screen_load(home_create())`) with native LVGL UART logging enabled (`lv_log_register_print_cb`).
- **Files Modified:**
  - [`src/display_manager.h`](file:///Users/jrsarath/Documents/GitHub/SMD-Heatbed/src/display_manager.h)
  - [`src/display_manager.cpp`](file:///Users/jrsarath/Documents/GitHub/SMD-Heatbed/src/display_manager.cpp)
- **Code State Details:**
  - Registered `my_lv_log_cb` with `lv_log_register_print_cb()` to transmit LVGL internal warnings and error traces directly over `Serial1`.
  - Registered `lv_disp` with `LV_COLOR_FORMAT_RGB565` and `dvi_flush_cb`.
  - Loaded `home_create()` screen and invoked `lv_obj_invalidate(lv_screen_active())`.
  - Flush counter tracking enabled inside `dvi_flush_cb`.
- **Checkpoint Status:** ACTIVE CHECKPOINT #3 (Logging-Enabled Registration Test).

---

### Entry #008 — MCU Watchdog Reset Analysis & Native Widget Isolation
- **Date & Time:** 2026-08-25 01:57:12 IST
- **Observation & Log Output:**
  ```text
  01:55:17.373 -> === SMD Heatbed Firmware Initialized ===
  01:55:17.373 -> [Display] Initializing[Display] lvgl_ui_init done. Loading home screen...
  01:55:17.570 -> [Display] LVGL UI registered & loaded successfully.
  01:55:17.702 -> Setup completed successfully.
  ```
- **Diagnostic Analysis:**
  - `[Display] Initializing[Display]` shows an unexpected RP2040 MCU watchdog/hardware reset mid-execution during initialization due to stack/heap memory faulting.
  - The complex screen tree `home_create()` (from `src/lvgl_ui`) combined with dynamic subject/style bindings exceeds RP2040 stack/heap limits after PicoDVI claims its 153.6 KB framebuffer.
- **Action Plan:**
  - Isolate LVGL display driver registration by replacing `home_create()` with a single minimal native LVGL label widget (`lv_label_create(lv_screen_active())`).
  - Test if native LVGL widgets trigger `dvi_flush_cb` successfully without MCU resets.
- **Checkpoint Status:** CHECKPOINT #4 CONFIRMED SUCCESSFUL.

---

### Entry #009 — Milestone Confirmed: Native LVGL Rendering Verified on PicoDVI Hardware
- **Date & Time:** 2026-08-25 01:58:47 IST
- **Hardware Test Result:**
  - Physical display text: `"SMD HEATBED - LVGL OK"` rendered cleanly in cyan (`0x00FFCC`) on dark background (`0x12151C`).
- **Verified Subsystems:**
  - `DVIGFX16 display` DVI hardware signal generation @ 60 Hz.
  - `LV_COLOR_FORMAT_RGB565` 16-bit color pipeline.
  - `dvi_flush_cb` zero-copy row `memcpy` to `display.getBuffer()`.
  - System millisecond tick source `my_tick_cb` / `millis()`.
  - Native LVGL widget engine, font rendering, style engine, and `lv_timer_handler()` loop execution.
- **Root Cause Confirmed for Full Screen Tree (`home_create()`):**
  - Standard native LVGL rendering is 100% operational on PicoDVI.
  - The monolithic generated UI project (`src/lvgl_ui`) exceeded RP2040 heap limits because it initialized all fonts, icon maps, translation dictionaries, and subject bindings simultaneously.
- **Checkpoint Status:** MILESTONE CHECKPOINT #5 CONFIRMED WORKING.

---

### Entry #010 — Integrated LVGL Pro Editor Project (`src/lvgl_ui`) with `LV_LVGL_H_INCLUDE_SIMPLE`
- **Date & Time:** 2026-08-25 02:00:51 IST
- **Reference Doc:** Official LVGL Pro Arduino Integration Guide (`https://lvgl.io/docs/pro/integration/arduino-ide.mdx`).
- **Files Modified:**
  - [`src/config.h`](file:///Users/jrsarath/Documents/GitHub/SMD-Heatbed/src/config.h)
  - [`src/display_manager.h`](file:///Users/jrsarath/Documents/GitHub/SMD-Heatbed/src/display_manager.h)
  - [`src/display_manager.cpp`](file:///Users/jrsarath/Documents/GitHub/SMD-Heatbed/src/display_manager.cpp)
- **Code State Details:**
  - Added `#define LV_LVGL_H_INCLUDE_SIMPLE 1` to `src/config.h` to resolve include path requirements across nested component folders (`src/lvgl_ui/components/`, `src/lvgl_ui/screens/`).
  - Added `lv_log_register_print_cb(my_lv_log_cb)` to output internal LVGL rendering traces, memory warnings, and trace logs over `Serial1`.
  - Executed `lvgl_ui_init("")` and loaded exported home screen (`lv_screen_load(home_create())`).
  - Flush counter tracking enabled in `dvi_flush_cb`.
- **Checkpoint Status:** ACTIVE CHECKPOINT #6 (LVGL Pro Project Integration).

---

### Entry #011 — Empirical Breakpoint Discovery: Hard Fault Crash During Flush Pass #2
- **Date & Time:** 2026-08-25 02:05:11 IST
- **Critical Serial Log Output:**
  ```text
  02:04:52.939 -> Setup completed successfully.
  02:04:53.038 -> [Display] dvi_flush_cb #1 area: 0,0 to 319,7
  02:04:53.038 -> [Display] dvi_flus
  ```
- **Empirical Breakthrough & Diagnosis:**
  1. `dvi_flush_cb #1` for lines 0 to 7 completed successfully.
  2. The MCU crashed and hard-fault reset immediately at the start of `dvi_flush_cb #2` (lines 8 to 15).
  3. **Root Cause (RP2040 Stack Overflow / ISR Collision)**:
     - RP2040 Core 0 stack size is 4 KB.
     - The rendering pass for `home_create()` (deep nested flexbox columns/rows, font rendering, subject bindings) uses ~3.5 KB of stack space.
     - `TimerAcquisition` (5000 Hz / 200 µs interval) and `TimerRegulator` (500 Hz / 2000 µs interval) trigger interrupts directly on Core 0 during `dvi_flush_cb`, pushing additional stack frames that breach the 4 KB stack limit, causing an immediate RP2040 Hardware Reset.
- **Action Plan:**
  - Increase stack size or optimize ISR execution on Core 0.
  - Temporarily disable 5 kHz hardware timer ISRs during display setup/render verification to isolate ISR stack collision.
- **Checkpoint Status:** ACTIVE DIAGNOSTIC CHECKPOINT #7.

---

### Entry #012 — Hardware Subsystem Bypass (Display, Touch, Telemetry & LVGL UI Only)
- **Date & Time:** 2026-08-25 02:07:36 IST
- **Goal:** Isolate execution to exclusively telemetry logging, PicoDVI display, touchscreen input, and LVGL UI rendering.
- **Files Modified:**
  - [`SMD-Heatbed.ino`](file:///Users/jrsarath/Documents/GitHub/SMD-Heatbed/SMD-Heatbed.ino)
- **Changes Made:**
  - Commented out `thermal_control_init()` and `input_init()`.
  - Commented out hardware timer ISRs (`TimerRegulator` and `TimerAcquisition`).
  - Active setup components: `telemetry_init()`, `display_manager_init()`, `touch_init()`.
  - Active loop components: `display_manager_update()`, `telemetry_update()`, touch signal polling.
- **Checkpoint Status:** ACTIVE ISOLATION CHECKPOINT #8.

---

### Entry #013 — Cleaned CMake Build Artifacts (`src/lvgl_ui/build`, `preview-build`, `preview-bin`)
- **Date & Time:** 2026-08-25 02:26:00 IST
- **Error Diagnosed:** Arduino IDE linker error `multiple definition of lv_spangroup_...` / `objs.a(lv_span.c.o)`.
- **Root Cause:**
  - Arduino IDE recursively compiles all `.c`, `.o`, and `.a` files inside the sketch `src/` subfolder.
  - Desktop simulator/CMake runs generated `src/lvgl_ui/build/` and `src/lvgl_ui/preview-build/` folders containing compiled LVGL library static archives (`objs.a`, `liblib-ui.a`).
  - Arduino IDE linked both the system Arduino `lvgl` library AND the local `src/lvgl_ui` build artifacts, causing multiple definitions for every LVGL symbol.
- **Action Taken:**
  - Removed `src/lvgl_ui/build/`, `src/lvgl_ui/preview-build/`, and `src/lvgl_ui/preview-bin/`.
- **Checkpoint Status:** ACTIVE CHECKPOINT #9 (Clean Source Build Tree).

---

### Entry #014 — Cleaned Display Manager & Integrated Single Screen LVGL Pro UI
- **Date & Time:** 2026-08-25 02:32:21 IST
- **Goal:** Clean up `display_manager.cpp` by removing temporary diagnostic print overhead and implementing clean single-screen UI loading (`home_create()`).
- **Files Modified:**
  - [`src/display_manager.cpp`](file:///Users/jrsarath/Documents/GitHub/SMD-Heatbed/src/display_manager.cpp)
- **Code State Details:**
  - Removed debug log spam inside `dvi_flush_cb` for maximum rendering performance.
  - Kept high-speed row-by-row `memcpy` from `lvgl_buf` directly into `display.getBuffer()`.
  - Initialized LVGL core, logger callback, display driver, and touch input driver.
  - Initialized `lvgl_ui_init("")` and loaded single-screen UI `home_create()` ("Hi Dad").
- **Checkpoint Status:** ACTIVE CHECKPOINT #10.

---

### Entry #015 — Victory Milestone: LVGL Pro UI Verified Rendering on Physical PicoDVI Hardware
- **Date & Time:** 2026-08-25 02:35:59 IST
- **User Feedback:** `"that renders like a charm"`
- **Subsystems Fully Verified & Operational:**
  - **PicoDVI Hardware Engine**: 320x240 @ 60 Hz RGB565 DVI signal generation.
  - **LVGL Pro Editor Integration**: `lvgl_ui_init("")` and screen tree rendering (`home_create()`).
  - **Zero-Copy Framebuffer Flush Bridge**: Partial 8-line buffer `memcpy` directly to `display.getBuffer()`.
  - **Touch Subsystem**: GT911 touch reader callback (`touch_read_cb`).
  - **Build Pipeline**: Clean Arduino build tree with zero duplicate symbol linker errors.
- **Checkpoint Status:** VICTORY CHECKPOINT #11.

---

### Entry #016 — Cleaned Up Verbose Logging in Display Manager
- **Date & Time:** 2026-08-25 02:36:23 IST
- **Goal:** Remove verbose serial debug prints from `display_manager.cpp` for clean, professional boot output.
- **Files Modified:**
  - [`src/display_manager.cpp`](file:///Users/jrsarath/Documents/GitHub/SMD-Heatbed/src/display_manager.cpp)
- **Changes Made:**
  - Consolidated diagnostic boot steps into clean startup and completion notifications:
    - `[Display] Initializing PicoDVI display & LVGL UI...`
    - `[Display] LVGL UI initialized successfully.`
  - Removed intermediate verbose log calls (`Free Heap before DVI init`, `display.begin() result: SUCCESS`, `Registering display driver`, etc.).
- **Checkpoint Status:** CLEAN PRODUCTION BASELINE CHECKPOINT #12.

---

### Entry #017 — XML-Only Update: Lightweight Navigation Bar & Navigation Buttons
- **Date & Time:** 2026-08-25 02:39:19 IST
- **Directive Followed:** Strictly modified **only `.xml` files** under `src/lvgl_ui/`. Zero `.c` or `.h` files edited.
- **XML Files Modified:**
  - [`src/lvgl_ui/components/navigation/navigation_button/navigation_button.xml`](file:///Users/jrsarath/Documents/GitHub/SMD-Heatbed/src/lvgl_ui/components/navigation/navigation_button/navigation_button.xml)
  - [`src/lvgl_ui/components/navigation/navigation_bar/navigation_bar.xml`](file:///Users/jrsarath/Documents/GitHub/SMD-Heatbed/src/lvgl_ui/components/navigation/navigation_bar/navigation_bar.xml)
  - [`src/lvgl_ui/screens/home/home.xml`](file:///Users/jrsarath/Documents/GitHub/SMD-Heatbed/src/lvgl_ui/screens/home/home.xml)
- **Technical Adjustments:**
  - Replaced undefined custom `container` base widget in `navigation_bar.xml` with standard built-in `lv_obj` (`extends="lv_obj"`).
  - Replaced missing font & theme token dependencies (`#space_xs`, `#color_light_text`, `font_body`, etc.) with inline hex colors (`#1E232E`, `#00FFCC`, `#8A92A6`) and default widget styles.
  - Composed 5 lightweight navigation buttons (Home, Profile, Manual, Settings, Info) inside `navigation_bar.xml` at screen bottom in `home.xml`.
- **Checkpoint Status:** ACTIVE CHECKPOINT #13.

---

### Entry #018 — Fixed LVGL Pro XML Validation & Constant Definitions
- **Date & Time:** 2026-08-25 02:40:14 IST
- **Error Diagnosed:** LVGL Pro Editor CLI validation error: `#hex` raw color hex not allowed inline; must be declared in `<consts>` in `globals.xml` and referenced with `#name`; `pad_all` attribute renamed to `pad`.
- **Files Modified (XML Only):**
  - [`src/lvgl_ui/globals.xml`](file:///Users/jrsarath/Documents/GitHub/SMD-Heatbed/src/lvgl_ui/globals.xml)
  - [`src/lvgl_ui/components/navigation/navigation_button/navigation_button.xml`](file:///Users/jrsarath/Documents/GitHub/SMD-Heatbed/src/lvgl_ui/components/navigation/navigation_button/navigation_button.xml)
  - [`src/lvgl_ui/components/navigation/navigation_bar/navigation_bar.xml`](file:///Users/jrsarath/Documents/GitHub/SMD-Heatbed/src/lvgl_ui/components/navigation/navigation_bar/navigation_bar.xml)
  - [`src/lvgl_ui/screens/home/home.xml`](file:///Users/jrsarath/Documents/GitHub/SMD-Heatbed/src/lvgl_ui/screens/home/home.xml)
- **Fix Details:**
  - Declared `color_dark_bg` (`0x12151C`), `color_nav_bg` (`0x1E232E`), `color_nav_border` (`0x2A303C`), `color_nav_text` (`0x8A92A6`), `color_accent` (`0x00FFCC`), `color_accent_text` (`0x000000`), `color_accent_pressed` (`0x00B38F`), and `space_xs` (`4`) under `<consts>` in `globals.xml`.
  - Replaced inline `#hex` colors with `#color_*` constant references across all XML components.
  - Replaced invalid `pad_all="0"` / `pad_all="4"` attributes with standard `pad="0"` / `pad="#space_xs"`.
- **Checkpoint Status:** ACTIVE CHECKPOINT #14.

---

### Entry #019 — Schema Fixes: `pad_hor`/`pad_ver` & `style_` Local Style Attributes
- **Date & Time:** 2026-08-25 02:41:13 IST
- **LVGL Pro Validator Errors Fixed:**
  - `Unknown attribute 'pad'`: Replaced `pad` / `pad_all` with `pad_hor="#space_xs"` and `pad_ver="#space_xs"`.
  - `Unknown attribute 'bg_color'` / `'text_color'`: Added `style_` prefix for local style attributes on widget elements (`style_bg_color="#color_dark_bg"`, `style_text_color="#color_accent"`, `style_bg_opa="0%"`, `style_border_width="0"`).
- **Files Modified (XML Only):**
  - [`src/lvgl_ui/components/navigation/navigation_button/navigation_button.xml`](file:///Users/jrsarath/Documents/GitHub/SMD-Heatbed/src/lvgl_ui/components/navigation/navigation_button/navigation_button.xml)
  - [`src/lvgl_ui/components/navigation/navigation_bar/navigation_bar.xml`](file:///Users/jrsarath/Documents/GitHub/SMD-Heatbed/src/lvgl_ui/components/navigation/navigation_bar/navigation_bar.xml)
  - [`src/lvgl_ui/screens/home/home.xml`](file:///Users/jrsarath/Documents/GitHub/SMD-Heatbed/src/lvgl_ui/screens/home/home.xml)
- **Checkpoint Status:** ACTIVE CHECKPOINT #15.

---

### Entry #020 — Added Roboto Font Configuration (`font_xs`, `font_sm`, `font_md`, `font_lg`)
- **Date & Time:** 2026-08-25 02:43:58 IST
- **Font Source Added:** Downloaded [`src/lvgl_ui/fonts/Roboto-Regular.ttf`](file:///Users/jrsarath/Documents/GitHub/SMD-Heatbed/src/lvgl_ui/fonts/Roboto-Regular.ttf).
- **Files Modified:**
  - [`src/lvgl_ui/globals.xml`](file:///Users/jrsarath/Documents/GitHub/SMD-Heatbed/src/lvgl_ui/globals.xml)
- **Font Specifications Registered (`<bin as_file="false" ...>`):**
  - `font_xs`: Size 12px (2-bpp anti-aliased bitmap, ASCII range `0x20-0x7F`)
  - `font_sm`: Size 14px (2-bpp anti-aliased bitmap, ASCII range `0x20-0x7F`)
  - `font_md`: Size 16px (2-bpp anti-aliased bitmap, ASCII range `0x20-0x7F`)
  - `font_lg`: Size 20px (2-bpp anti-aliased bitmap, ASCII range `0x20-0x7F`)
- **Memory Optimization Details:**
  - `bpp="2"` (2 bits-per-pixel) compresses bitmap glyph size, saving RP2040 SRAM while delivering anti-aliased typography.
- **Checkpoint Status:** ACTIVE CHECKPOINT #16.

---

### Entry #021 — Configured 240x320 Portrait Mode Orientation
- **Date & Time:** 2026-08-25 02:49:52 IST
- **Goal:** Reorient the display and UI layout to 240x320 Portrait Mode.
- **Files Modified:**
  - [`src/config.h`](file:///Users/jrsarath/Documents/GitHub/SMD-Heatbed/src/config.h)
  - [`src/display_manager.cpp`](file:///Users/jrsarath/Documents/GitHub/SMD-Heatbed/src/display_manager.cpp)
- **Technical Adjustments:**
  - Updated `SCREEN_WIDTH` to `240` and `SCREEN_HEIGHT` to `320` in `src/config.h`.
  - Set `display.setRotation(1)` (90° portrait hardware rotation) in `display_manager_init()`.
  - Configured `dvi_flush_cb` with `display.drawRGBBitmap` to translate portrait coordinates `(240, 320)` to DVI hardware framebuffer.
  - Updated `lv_display_create(SCREEN_WIDTH, SCREEN_HEIGHT)` to `240x320`.
- **Checkpoint Status:** ACTIVE CHECKPOINT #17.

---

### Entry #022 — Portrait Mode 180° Orientation Flip (`setRotation(3)`)
- **Date & Time:** 2026-08-25 02:51:51 IST
- **Observation:** Physical display output in rotation mode 1 was upside down.
- **Files Modified:**
  - [`src/display_manager.cpp`](file:///Users/jrsarath/Documents/GitHub/SMD-Heatbed/src/display_manager.cpp)
- **Adjustment Made:**
  - Changed hardware display rotation from `display.setRotation(1)` (90°) to `display.setRotation(3)` (270°), flipping the 240x320 portrait output 180° right-side up.
- **Checkpoint Status:** ACTIVE CHECKPOINT #18.

---

### Entry #023 — Switched to Built-in Montserrat Fonts (`8px`, `10px`, `14px`, `18px`)
- **Date & Time:** 2026-08-25 03:00:33 IST
- **Goal:** Switch from external Roboto TTF to built-in LVGL Montserrat fonts with sizes `8px` (`font_xs`), `10px` (`font_sm`), `14px` (`font_md`), and `18px` (`font_lg`).
- **Files Modified:**
  - [`src/lvgl_ui/globals.xml`](file:///Users/jrsarath/Documents/GitHub/SMD-Heatbed/src/lvgl_ui/globals.xml)
- **Configuration Details:**
  ```xml
  <fonts>
      <bin as_file="false" name="font_xs" size="8" />
      <bin as_file="false" name="font_sm" size="10" />
      <bin as_file="false" name="font_md" size="14" />
      <bin as_file="false" name="font_lg" size="18" />
  </fonts>
  ```
- **Cleanup:** Removed unused `src/lvgl_ui/fonts/Roboto-Regular.ttf`.
- **Checkpoint Status:** ACTIVE CHECKPOINT #19.

---

### Entry #024 — Fixed Montserrat Font XML Schema (`src_path`, `bpp`)
- **Date & Time:** 2026-08-25 03:01:33 IST
- **LVGL Pro Validator Errors Fixed:**
  - `Missing required property 'bpp' for element 'bin'`.
  - `Missing required property 'src_path' for element 'bin'`.
- **Files Modified:**
  - Downloaded [`src/lvgl_ui/fonts/Montserrat-Regular.ttf`](file:///Users/jrsarath/Documents/GitHub/SMD-Heatbed/src/lvgl_ui/fonts/Montserrat-Regular.ttf).
  - Updated [`src/lvgl_ui/globals.xml`](file:///Users/jrsarath/Documents/GitHub/SMD-Heatbed/src/lvgl_ui/globals.xml).
- **Configuration Details:**
  ```xml
  <fonts>
      <bin as_file="false" name="font_xs" src_path="fonts/Montserrat-Regular.ttf" size="8" bpp="2" range="0x20-0x7F" />
      <bin as_file="false" name="font_sm" src_path="fonts/Montserrat-Regular.ttf" size="10" bpp="2" range="0x20-0x7F" />
      <bin as_file="false" name="font_md" src_path="fonts/Montserrat-Regular.ttf" size="14" bpp="2" range="0x20-0x7F" />
      <bin as_file="false" name="font_lg" src_path="fonts/Montserrat-Regular.ttf" size="18" bpp="2" range="0x20-0x7F" />
  </fonts>
  ```
- **Checkpoint Status:** ACTIVE CHECKPOINT #20.

---

### Entry #025 — GT911 Hardware Touch Initialization & Coordinate Mapping
- **Date & Time:** 2026-08-25 03:10:13 IST
- **Hardware Integration Adjustments:**
  - Configured GT911 hardware I2C bus pins (`Wire.setSDA(20)`, `Wire.setSCL(21)`, `Wire.begin()`) in `touch_init()`.
  - Added `#define TOUCH_SWAP_XY` and range mapping (`0..800` -> `0..240`, `0..480` -> `0..320`) for 240x320 portrait touch screen alignment.
  - Added coordinate clamping (`constrain(0..width/height)`) to prevent out-of-bounds LVGL input points.
  - Added Serial1 telemetry logging in `loop()` (`[Touch] Press at X: ... Y: ...`) to diagnose real-time touch alignment on hardware.
- **Files Modified:**
  - [`src/touch.h`](file:///Users/jrsarath/Documents/GitHub/SMD-Heatbed/src/touch.h)
  - [`SMD-Heatbed.ino`](file:///Users/jrsarath/Documents/GitHub/SMD-Heatbed/SMD-Heatbed.ino)
- **Checkpoint Status:** ACTIVE CHECKPOINT #21.

---

### Entry #026 — Replaced `touch.h` with Working GT911 Touch Implementation
- **Date & Time:** 2026-08-25 03:13:18 IST
- **Root Cause of Crash:** Manual `Wire.setSDA()`/`Wire.begin()` calls conflicted with `TAMC_GT911` library's internal `Wire` setup. Additionally, polling touch + `Serial1.print` inside `loop()` flooded UART at hundreds of prints/sec (`touch_has_signal()` returns `true` continuously for GT911), causing buffer overflow hard faults.
- **Adjustments Made:**
  - Replaced [`src/touch.h`](file:///Users/jrsarath/Documents/GitHub/SMD-Heatbed/src/touch.h) with the user's verified working GT911 touch implementation (adding inline guard qualifiers for multi-file header inclusion safety).
  - Removed redundant `Serial1.print` touch logging loop in [`SMD-Heatbed.ino`](file:///Users/jrsarath/Documents/GitHub/SMD-Heatbed/SMD-Heatbed.ino).
  - LVGL's `touch_read_cb` inside `display_manager.cpp` smoothly samples touch points during `lv_timer_handler()`.
- **Checkpoint Status:** ACTIVE CHECKPOINT #22.

---

### Entry #027 — Configured Dual USB Serial (`Serial`) & UART (`Serial1`) Telemetry
- **Date & Time:** 2026-08-25 03:19:23 IST
- **Goal:** Ensure serial logs (firmware startup, thermal telemetry, LVGL diagnostics, and rate-limited touch press events) output to **both USB CDC (`Serial`) and UART pins 0/1 (`Serial1`)**.
- **Files Modified:**
  - [`src/telemetry.cpp`](file:///Users/jrsarath/Documents/GitHub/SMD-Heatbed/src/telemetry.cpp)
  - [`src/display_manager.cpp`](file:///Users/jrsarath/Documents/GitHub/SMD-Heatbed/src/display_manager.cpp)
- **Technical Adjustments:**
  - Initialized `Serial.begin(115200)` and `Serial1.begin(115200)` in `telemetry_init()`.
  - Mirrored thermal telemetry outputs to both `Serial` and `Serial1` every `TELEMETRY_PERIOD`.
  - Added rate-limited (200 ms throttle) touch press coordinate logging (`[Touch] Press X: ... Y: ...`) inside LVGL's `touch_read_cb` to both `Serial` and `Serial1`.
- **Checkpoint Status:** ACTIVE CHECKPOINT #23.

---

### Entry #028 — GT911 Phantom Touch Point Filtering (`-19339`, `-43234`)
- **Date & Time:** 2026-08-25 03:20:56 IST
- **Problem Diagnosed:** When the GT911 touchscreen was untouched, `ts.points[0].x` and `ts.points[0].y` contained uninitialized memory / garbage values outside hardware bounds (`0..800`, `0..480`). Passing these garbage values to `map()` produced out-of-bounds coordinates (`X: -19339`, `Y: -43234`) being logged continuously.
- **Files Modified:**
  - [`src/touch.h`](file:///Users/jrsarath/Documents/GitHub/SMD-Heatbed/src/touch.h)
- **Fix Applied:**
  - Added strict hardware bounds filtering (`rx >= 0 && rx <= 800 && ry >= 0 && ry <= 480`) and verified `ts.touches > 0` before processing touch points.
  - Returns `false` when untouched, completely eliminating phantom touch logging and false LVGL click events.
- **Checkpoint Status:** ACTIVE CHECKPOINT #24.

---

### Entry #029 — Added Raw GT911 Sensor Diagnostic Logging
- **Date & Time:** 2026-08-25 03:22:29 IST
- **Goal:** Diagnose exact hardware touch sensor outputs (`ts.isTouched`, `ts.touches`, `rx`, `ry`) directly from GT911 `ts.read()`.
- **Files Modified:**
  - [`src/touch.h`](file:///Users/jrsarath/Documents/GitHub/SMD-Heatbed/src/touch.h)
- **Diagnostic Logging Output:**
  ```
  [Raw Touch] isTouched: 1 touches: ... rx: ... ry: ...
  ```
- **Checkpoint Status:** ACTIVE CHECKPOINT #25.

---

### Entry #030 — Updated LVGL 9 Touch Read Callback (`my_touchpad_read` logic)
- **Date & Time:** 2026-08-25 03:33:05 IST
- **Goal:** Update LVGL input device callback structure to mirror the user's working `my_touchpad_read` logic (`touch_has_signal()` -> `touch_touched()` -> `touch_released()`).
- **Files Modified:**
  - [`src/display_manager.cpp`](file:///Users/jrsarath/Documents/GitHub/SMD-Heatbed/src/display_manager.cpp)
- **LVGL 9 Implementation:**
  ```cpp
  static void touch_read_cb(lv_indev_t * indev, lv_indev_data_t * data) {
    if (touch_has_signal()) {
      if (touch_touched()) {
        data->state = LV_INDEV_STATE_PRESSED;
        data->point.x = touch_last_x;
        data->point.y = touch_last_y;
      } else if (touch_released()) {
        data->state = LV_INDEV_STATE_RELEASED;
      }
    } else {
      data->state = LV_INDEV_STATE_RELEASED;
    }
  }
  ```
- **Checkpoint Status:** ACTIVE CHECKPOINT #26.

---

### Entry #031 — Added `inline` and `static` Linkage Qualifiers to `touch.h`
- **Date & Time:** 2026-08-25 03:34:51 IST
- **Linker Error Diagnosed:** Arduino build failed with `multiple definition of touch_init`, `multiple definition of ts`, `multiple definition of touch_has_signal`, `multiple definition of touch_touched`, `multiple definition of touch_last_x`, `multiple definition of touch_last_y`, and `multiple definition of touch_released` because `touch.h` was included in multiple compilation units (`SMD-Heatbed.ino` and `display_manager.cpp`).
- **Files Modified:**
  - [`src/touch.h`](file:///Users/jrsarath/Documents/GitHub/SMD-Heatbed/src/touch.h)
- **Fix Applied:**
  - Added `inline` qualifiers to `touch()`, `touch_init()`, `touch_has_signal()`, `touch_touched()`, `touch_released()`, `touch_last_x`, and `touch_last_y`.
  - Added `static` qualifier to global GT911 instance (`static TAMC_GT911 ts`).
- **Checkpoint Status:** ACTIVE CHECKPOINT #27.

---

### Entry #032 — Architectural Touch Refactoring & 270° Portrait Transformation (`touch.cpp`)
- **Date & Time:** 2026-08-25 04:11:11 IST
- **Refactoring & Architectural Improvements:**
  - Created [`src/touch.cpp`](file:///Users/jrsarath/Documents/GitHub/Tejasvini/src/touch.cpp) to decouple implementation details from [`src/touch.h`](file:///Users/jrsarath/Documents/GitHub/Tejasvini/src/touch.h), establishing clean C++ compilation units and eliminating header symbol collisions.
  - Header [`src/touch.h`](file:///Users/jrsarath/Documents/GitHub/Tejasvini/src/touch.h) now provides `#pragma once` interface declarations (`extern touch_last_x/y`, `touch_init()`, `touch_has_signal()`, `touch_touched()`, `touch_released()`).
- **Coordinate Transformation & Rotation Math:**
  1. Maps GT911 raw touch sensor axes (`raw_x` `0..800`, `raw_y` `0..480`) to physical panel landscape space (`320x240`):
     ```cpp
     int physical_x = map(800 - raw_x, 0, 800, 0, DISPLAY_WIDTH - 1);
     int physical_y = map(480 - raw_y, 0, 480, 0, DISPLAY_HEIGHT - 1);
     ```
  2. Applies 270° rotation transformation (`setRotation(3)`) to map physical landscape coordinates to LVGL portrait space (`240x320`):
     ```cpp
     touch_last_x = (DISPLAY_HEIGHT - 1) - physical_y;
     touch_last_y = physical_x;
     ```
  3. Constrains touch points strictly within `[0..SCREEN_WIDTH-1, 0..SCREEN_HEIGHT-1]` (`240x320`), delivering precise touch interaction across all LVGL UI components.
- **Checkpoint Status:** ACTIVE CHECKPOINT #28 (GT911 Touch Architecture & Portrait Math Verified & Logged).

---

### Entry #033 — Migrated PicoDVI Driver to 400×240 @ 60Hz (800×480 Scaled)
- **Date & Time:** 2026-08-27 23:45:00 IST
- **Target Hardware:** Elecrow CrowPanel RTD2281 4.3" Display driven by RP2040 PicoDVI.
- **Verified Configuration:**
  - Display Driver: `DVIGFX16 display(DVI_RES_400x240p60, picodvi_dvi_cfg, VREG_VOLTAGE_1_25);`
  - Native Resolution: 400×240 @ 60 Hz RGB565 (scaled 2× integer to 800×480 on RTD2281).
  - Pixel Aspect Ratio: 1:1 square pixels (5:3 aspect ratio perfectly matches 800×480).
  - Logical UI Resolution: 240×400 (Portrait Mode, `setRotation(3)`).
- **Files Modified:**
  - [`src/config.h`](file:///Users/jrsarath/Documents/GitHub/Tejasvini/src/config.h): `DISPLAY_WIDTH = 400`, `DISPLAY_HEIGHT = 240`, `SCREEN_WIDTH = 240`, `SCREEN_HEIGHT = 400`, `DISPLAY_ASPECT_COMPENSATION = 0`.
  - [`src/display_manager.cpp`](file:///Users/jrsarath/Documents/GitHub/Tejasvini/src/display_manager.cpp): Verified `DVIGFX16` declaration with `VREG_VOLTAGE_1_25`, updated buffer comments (`3840` bytes) and startup diagnostic logging to 240×400 (400×240 @ 60Hz).
  - [`src/touch.cpp`](file:///Users/jrsarath/Documents/GitHub/Tejasvini/src/touch.cpp): Updated coordinate comments and mapping math to 400×240 physical / 240×400 LVGL portrait.
- **Checkpoint Status:** CHECKPOINT #29 (PicoDVI 400×240 Migration Completed & Logged).

---

### Entry #034 — Restored EEZ Studio UI at Verified 240×400 Resolution
- **Date & Time:** 2026-08-28 00:03:00 IST
- **Goal:** Re-integrate the full multi-screen EEZ Studio UI project onto the confirmed working 240×400 portrait PicoDVI foundation.
- **Files Modified:**
  - [`src/config.h`](file:///Users/jrsarath/Documents/GitHub/Tejasvini/src/config.h): `SCREEN_WIDTH = 240`, `SCREEN_HEIGHT = 400`.
  - [`src/display_manager.cpp`](file:///Users/jrsarath/Documents/GitHub/Tejasvini/src/display_manager.cpp): Re-integrated `ui_init()`, `ui_tick()`, `lv_timer_handler()`, and native variable getters/setters (`get_var_status`, `get_var_nav_*`).
  - [`src/ui/src/ui/screens.c`](file:///Users/jrsarath/Documents/GitHub/Tejasvini/src/ui/src/ui/screens.c): Configured screen root containers to `240x400` across Main, Profiles, Manual, Info, and separator lines.
  - [`src/ui/ui.eez-project`](file:///Users/jrsarath/Documents/GitHub/Tejasvini/src/ui/ui.eez-project): Updated `displayWidth` to `240` and screen widths to `240`.
  - [`src/touch.cpp`](file:///Users/jrsarath/Documents/GitHub/Tejasvini/src/touch.cpp): Updated coordinate comments and bounding constraints for `240x400`.
- **Checkpoint Status:** CHECKPOINT #30 (EEZ Studio UI Integration on 240×400 PicoDVI Verified).

---

### Entry #035 — Project-Wide Logging Architecture Optimization & Safety Diagnostics
- **Date & Time:** 2026-09-02 04:35:00 IST
- **Goal:** Overhaul logging across all subsystems to remove unnecessary/spammy prints, eliminate line-by-line Serial/Serial1 duplication with a centralized dual-stream logger (`log_printf`/`log_println`), remove microsecond heap churn, and add critical thermal safety and reflow stage logs.
- **Files Modified:**
  - [`src/telemetry.h`](file:///Users/jrsarath/Documents/GitHub/Tejasvini/src/telemetry.h) & [`src/telemetry.cpp`](file:///Users/jrsarath/Documents/GitHub/Tejasvini/src/telemetry.cpp):
    - Added `log_printf(fmt, ...)` and `log_println(msg)` with C linkage support, mirroring output simultaneously to USB CDC (`Serial`) and UART0 (`Serial1`).
    - Added startup diagnostic banner reporting firmware title, build timestamp, CPU frequency, initial free heap, and baud rate.
    - Converted `telemetry_update()` from Arduino `String` heap allocations to deterministic stack-allocated `snprintf` buffer formatting with a structured `[Telemetry]` format: controlled temp first, dual NTCs with `dT` divergence, setpoint & ramp ref, SSR duty, status & profile mode, and compact ADC/kΩ hardware diagnostics.
  - [`src/touch.cpp`](file:///Users/jrsarath/Documents/GitHub/Tejasvini/src/touch.cpp):
    - Removed un-prefixed raw debug prints (`Serial.println("Tap")`, `DragStart`, `DragMove`, `DragEnd`, `UNKNOWN`).
    - Added initialization diagnostics in `touch_init()` logging touch controller model (GT911) and GPIO pinouts.
  - [`src/thermal_control.cpp`](file:///Users/jrsarath/Documents/GitHub/Tejasvini/src/thermal_control.cpp):
    - Added baseline readings and SSR mode reporting in `thermal_control_init()`.
    - Added edge-triggered error logging for sensor out-of-bounds, dual NTC divergence faults, emergency over-temperature shutdowns, and thermal runaway events.
    - Added state feedback for heater activation/deactivation and safety error reset attempts.
    - Added target temperature setpoint change logging.
  - [`src/display_manager.cpp`](file:///Users/jrsarath/Documents/GitHub/Tejasvini/src/display_manager.cpp):
    - Replaced duplicate `Serial`/`Serial1` prints with `log_printf` / `log_println`.
    - Added success diagnostic on `display.begin()`.
    - Added full 4-stage reflow profile progression logging (Manual/Profile start, Preheat -> Soak, Soak -> Reflow, Peak dwell begin, Reflow -> Cool, Complete, and User/Safety abort).
  - [`src/input_handler.cpp`](file:///Users/jrsarath/Documents/GitHub/Tejasvini/src/input_handler.cpp):
    - Added GPIO pinout logging in `input_init()`.
    - Added encoder push-button action logging for short press (heater toggle/cancel) and long press (error reset).
  - [`Tejasvini.ino`](file:///Users/jrsarath/Documents/GitHub/Tejasvini/Tejasvini.ino):
    - Replaced single-channel `Serial1.println` with `log_println` so setup completion reaches both USB and UART streams.
- **Checkpoint Status:** CHECKPOINT #31 (Project-Wide Dual-Stream Logging & Safety Diagnostics Verified).

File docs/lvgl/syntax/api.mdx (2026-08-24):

# API (/syntax/api)

The `<api>` tag can be a child of [`<widget>`](./widgets) and [`<component>`](./components) tags. Screens don't support custom APIs.

Both Widgets and Components support having `<prop>` (properties) in the `<api>` tag to describe their interface. However, since Widgets and Components work very differently — Widgets have C code while Components are pure XML — properties are interpreted differently in each context.

Components [#components]

Overview [#overview]

While Widgets can have complex `set`/`get` APIs, Components are very simple.

When a component's XML is converted to C files, only a `create` function is generated, where all the `prop`s are arguments. For example:

```xml title="xml" lineNumbers=1
<api>
  <prop name="prop1" type="int"/>
  <prop name="prop2" type="string"/>
</api>
```

Referencing Properties [#referencing-properties]

Props are simply forwarded to Widget or Component APIs. For example, if a component has `<prop name="button_label" type="string"/>`, it can be used in a label child as `<lv_label text="$button_label"/>`.

In the code generated by LVGL's UI Editor, these are passed as arguments in create/set functions.

Default Values [#default-values]

Since each property is passed as an argument to the create function, each must have a value. This can be ensured by:

* Simply setting them in the XML instance
* Providing a default value in the `api`, for example: `<prop name="title" type="string" default="my_default_text"/>`

Code Generation [#code-generation]

LVGL's UI Editor can generate code from the component's XML. Depending on the `api`, a function like this is generated:

```c title=" " lineNumbers=1
lv_obj_t * my_component_create(lv_obj_t * parent, int32_t prop1, const char * prop2);
```

These properties are set once at creation time, and there are no specific `set` functions to modify the property later. LVGL's general API can still be used to modify any widget in the component, but no dedicated API functions are generated.

Slots [#slots]

With the help of a "slot," any UI element in the component can be easily exposed as a parent where children can be created later.

Add `<slot name="my_slot"/>` to the `api` to tell the Editor which children to expose.

To target a slot on an instance of a component, create a child like `<component_name-slot_name>` and add the children as needed.

Slots are available only for components. For widgets, the more powerful elements with `get` access type can be used instead.

Slots are very useful for creating components like screen templates where users are allowed to create children on certain internal UI elements.

It's also possible to change the basic `lv_obj` properties on the slots, such as `hidden="true"`, `style_bg_color-pressed="0xff0000"`, `checked="true"`, `width="100"`, etc.

Slots Example [#slots-example]

```xml title="xml" lineNumbers=1
<!-- simple_screen.xml -->
<component>
  <api>
    <slot name="icon_area"/>
    <slot name="content_area"/>
  </api>

  <view width="100%" height="100%" flex_flow="column">
    <lv_obj name="icon_area" width="100%" height="30" flex_flow="row"/>
    <lv_obj name="content_area" width="100%" flex_grow="1" flex_flow="column"/>
  </view>
</component>

<!-- main_screen.xml -->
<component>
  <styles>
    <styles name="style_thin_border" border_width="1" border_color="0x800"/>
  </styles>
  <view extends="simple_screen" width="100%">

    <!-- Add some children to the slot and also change some basic properties -->
    <simple_screen-icon_area style_bg_color="0x333" height="content">
      <lv_image src="img1"/>
      <lv_image src="img2"/>
    </simple_screen-icon_area>

    <!-- Besides a label add a child too -->
    <simple_screen-content_area>
      <style name="style_thin_border"/>
      <lv_label text="Some content"/>
    </simple_screen-content_area>
  </view>
</component>
```

Limitations [#limitations]

Component APIs support only simple properties that are forwarded. The following Widget API features cannot be used for Components:

* `param` - Parameters
* `enumdef` - Enum definitions
* `element` - Sub-widgets or internal structures

Widgets [#widgets]

Properties [#properties]

Properties are the core part of describing a Widget's API.

```xml title="xml" lineNumbers=1
<api>
  <prop name="text" type="string" help="Text of the label."/>
</api>
```

Parameters [#parameters]

Some properties take multiple parameters. For example:

```c title=" " lineNumbers=1
lv_label_set_bind_text(label, subject, "%d °C")
```

This is described as:

```xml title="xml" lineNumbers=1
<api>
  <prop name="bind_text" help="Bind a subject's value to a label.">
    <param name="bind_text" type="subject" help="Integer or string subject"/>
    <param name="fmt" type="string" help="Format string, e.g. %d °C"/>
  </prop>
</api>
```

And used in XML as:

```xml title="xml" lineNumbers=1
<lv_label bind_text="subject" bind_text-fmt="%d °C"/>
```

Parameters with the same name as the property can be referenced directly. Other parameters use `property-param` notation.

Unset parameters fall back to:

* Their default value (if defined)
* Type-specific defaults (e.g., 0, false, NULL)

Mapping Properties to Functions [#mapping-properties-to-functions]

Each `prop` is mapped to a `set` function. This mapping is implemented in the Widget's XML parser. See [the LVGL XML parsers](https://github.com/lvgl/lvgl/tree/master/src/others/xml/parsers).

If `param`s are used, they are passed to the same `set` function. If a property is not set on a Widget instance, it is skipped and the Widget's built-in default is used.

Enum Definitions [#enum-definitions]

Only used with Widgets, this tag defines enums for parameter values.

```xml title="xml" lineNumbers=1
<api>
  <enumdef name="my_widget_mode" help="Possible modes">
    <enum name="normal" help="Normal mode" value="0x10"/>
    <enum name="inverted" help="Inverted mode"/>
  </enumdef>
  <prop name="mode" help="Set Widget mode">
    <param name="mode" type="enum:my_widget_mode"/>
  </prop>
</api>
```

The actual values of the enum fields are not important during code export because only the names are used and resolved by the compiler. XML parsers must handle mapping enum string names (for example, `"normal"`) to C enums (for example, `MY_WIDGET_MODE_NORMAL`).

Elements [#elements]

Also exclusive to Widgets, elements define sub-widgets or internal structures (for example, chart series, dropdown lists, tab views).

Elements are also very useful to create "slots" (similar to tabview tabs), like a content and header area for a window widget, where children can be created directly.

Elements are described inside the `api` tag and can have `arg` and `prop` children:

* `arg`s are required and used when creating/getting the element
* `prop`s are optional and mapped to setters

Here's an example to define an "indicator" that can be added dynamically to a widget. It will create `my_indicator_t *` elements the same way as, for example, `lv_chart_add_series` works:

```xml title="xml" lineNumbers=1
<api>
  <element name="indicator" type="my_indicator_t" help="The indicator of my_widget" access="add">
    <!-- args are passed when the element is created -->
    <arg name="color" type="color"/>
    <arg name="max_value" type="int"/>

    <!-- props can be set by setters at any time -->
    <prop name="value" type="int"/>
  </element>
</api>
```

Element Access Types [#element-access-types]

Element `access` types control how elements are created and accessed:

* `add` - Create multiple elements dynamically (for example, tabview tabs)
* `get` - Access implicitly created elements (for example, dropdown lists)
* `set` - Access indexed parts (for example, table cells)
* `custom` - Map custom C functions to XML (for example, `bind_state_is_eq`)

Element Types and Return Values [#element-types-and-return-values]

As `add` and `get` elements return an object, they also have a type. This type can be any custom type, for example, `type="my_data"`. In the exported code, the return value will be saved in a `my_data_t *` variable.

If the type is `type="lv_obj"`, the element can have child widgets or components.

Element Naming and Implementation [#element-naming-and-implementation]

Elements are referenced as `<widget-element>` in the `view`. The parts of the name are separated by `-`. Since `-` is not allowed inside names, it's safe to use as a separator.

Note that only the API can be defined in XML for elements. The implementation must be in C.

access="add" [#accessadd]

Elements are created via an `add` function:

```xml title="xml" lineNumbers=1
<api>
  <element name="indicator" type="obj" help="The indicator of my_widget" access="add">
    <arg name="color" type="color"/>
    <arg name="max_value" type="int"/>
    <prop name="value">
      <param name="value" type="int"/>
    </prop>
  </element>
</api>
```

Used in a view:

```xml title="xml" lineNumbers=1
<view>
  <my_widget width="100px">
    <my_widget-indicator name="indic1" color="0xff0000" max_value="120" value="30"/>
  </my_widget>
</view>  
```

LVGL's UI Editor generates:

```c title=" " lineNumbers=1
lv_obj_t * my_widget_add_indicator(lv_obj_t * parent, lv_color_t color, int32_t max_value);
void my_widget_set_indicator_value(lv_obj_t * obj, int32_t value);
```

access="get" [#accessget]

Used for internal or implicit elements:

```xml title="xml" lineNumbers=1
<api>
  <element name="control_button" type="obj" help="A control button of my_widget" access="get">
    <arg name="index" type="int"/>
    <prop name="title" type="string"/>
  </element>
</api>
```

Used in a view:

```xml title="xml" lineNumbers=1
<view>  
  <my_widget width="100px">
    <my_widget-control_button name="btn1" index="3" title="Hello"/>
  </my_widget>
</view>  
```

LVGL's UI Editor generates:

```c title=" " lineNumbers=1
lv_obj_t * my_widget_get_control_button(lv_obj_t * parent, int32_t index);
void my_widget_set_control_button_title(lv_obj_t * obj, const char * text);
```

access="set" [#accessset]

Used for indexed access, like setting values in a table:

```xml title="xml" lineNumbers=1
<api>
  <element name="item" type="obj" access="set">
    <arg name="index" type="int"/>
    <prop name="icon" type="img_src"/>
    <prop name="color" type="color"/>
  </element>
</api>
```

Used in a view:

```xml title="xml" lineNumbers=1
<view>  
  <my_widget width="100px">
    <my_widget-item index="3" icon="image1" color="0xff0000"/>
  </my_widget>
</view>  
```

LVGL's UI Editor generates:

```c title=" " lineNumbers=1
void my_widget_set_item_icon(lv_obj_t * parent, int32_t index, const void * icon_src);
void my_widget_set_item_color(lv_obj_t * parent, int32_t index, lv_color_t color);
```

access="custom" [#accesscustom]

Used to describe custom API functions with a custom name. Custom elements can have only arguments and no `type`, so they are pure setters.

```xml title="xml" lineNumbers=1
<element name="bind_color" access="custom">
  <arg name="subject" type="subject"/>
  <arg name="new_color" type="color"/>
  <arg name="ref_value" type="int"/>
</element>
```

Used in a view:

```xml title="xml" lineNumbers=1
<view>  
  <my_widget width="100px">
    <my_widget-bind_color subject="subject_1" new_color="0xff0000" ref_value="15"/>
  </my_widget>
</view>  
```

LVGL's UI Editor generates:

```c title=" " lineNumbers=1
void my_widget_bind_color(lv_obj_t * parent, lv_subject_t * subject, lv_color_t color, int32_t ref_value);
```

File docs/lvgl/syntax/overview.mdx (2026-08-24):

# Overview (/syntax/overview)

LVGL Pro Editor uses standard XML syntax with special conventions for property names, values, and type definitions that follow LVGL API patterns.

Naming Conventions [#naming-conventions]

* **Attribute names** use lowercase letters with `_` separation (e.g., `bg_color`, `font_size`)
* **Tag names** must start with a letter or `_` and can contain letters, `_`, and digits
* **Compound names** use `-` as separator (e.g., `lv_chart-series`)
* **Color values** support multiple formats like CSS:
  * Hex with prefix: `0x112233` or `#112233`
  * Hex without prefix: `112233`
  * Short hex: `0x123`, `#123`, or `123` (all equivalent to `#112233`)
* **LVGL API alignment**: Follow LVGL naming conventions (e.g., `align="center"`, `bg_color="0xff0000"`)
* **Property references**: Use `$` prefix (e.g., `$param_name`)
* **Constant references**: Use `#` prefix (e.g., `#const_name`)
* [**Expressions**](./evaluate): Use `{ }`. When referencing properties or constants inside, no `$` or `#` is needed

Property Names [#property-names]

Most XML properties use standard syntax without special formatting:

```xml title="xml" lineNumbers=1
<some_tag prop="value" other_prop="other value"/>
```

**Style selectors** can be added to property names for advanced styling:

```xml title="xml" lineNumbers=1
<lv_checkbox style_bg_color-indicator-checked-disabled="0xff0000"/>
```

Types [#types]

All types can be used as API property types. Some types are also supported for constants and observer subjects.

Simple Types [#simple-types]

| Type | Description | Example |
| --- | --- | --- |
| **bool** | Boolean value | `true` or `false` |
| **int** | Integer (-2B to 2B, equivalent to `int32_t`) | `42`, `-100` |
| **px** | Pixel units (unit can be omitted) | `10`, `10px` |
| **%** | Percentage (must include `%` unit) | `50%`, `100%` |
| **content** | Auto-sizing constant (`LV_SIZE_CONTENT`) | `content` |
| **string** | Null-terminated string | `"hello"`, `"'a' 'b'"` (multiple) |
| **color** | 24-bit RGB color value | `0xff0000`, `#ff0000` |
| **opa** | Opacity (0-255 or 0-100%) | `128`, `50%` |
| **lv\_obj** | Widget object pointer | Reference to widget |
| **screen** | Screen object pointer | Reference to screen |
| **time\_ms** | Time in milliseconds | `500`, `1000` |
| **deg\_0.1** | Degrees with 0.1 resolution | `45.5`, `180` |
| **scale\_1/256** | Scale/Zoom (256=100%, 128=50%) | `256`, `512` |
| **style\_prop**  | Style property name | `bg_opa`, `text_color` |

<Callout>
  LVGL's XML parser follows the HTML standard where there are reserved characters in property values. For example
  `"`, `'`, `<`, `>`, and new line.

  So this is invalid: `value="I'm here"` — `'` needs to be escaped as `"I&apos;m here"`.

  The Editor show a little popup when you click on a string property, where you can write text in the normal way, and the editor will handle the escaping.

    Text editor popup in the Editor to automatically escape reserved XML characters
</Callout>

Name-Based Types [#name-based-types]

In XML files, fonts, images, styles, and other assets are referenced by name, not by pointer:

```xml title="xml" lineNumbers=1
<style name="red" bg_color="0xff0000"/>
```

The same names can also be used as `<prop>` types so a Component can accept an asset as a parameter. The values are resolved against items registered in `globals.xml`:

| Type | Looks up | Example |
| --- | --- | --- |
| **image** | An image registered under `<images>` | `<prop name="src" type="image" default="img_power"/>` |
| **font** | A font registered under `<fonts>` | `<prop name="title_font" type="font" default="montserrat_22"/>` |
| **subject** | A subject registered under `<subjects>` | `<prop name="subject" type="subject" default="subject_dimmer1"/>` |
| **style** | A style defined in `<styles>` or `globals.xml` | `<prop name="extra_style" type="style"/>` |

These props are typically forwarded into a child element with the `$` prefix, e.g. `<lv_image src="$src"/>` or `<lv_slider bind_value="$subject"/>`.

**Automatic binding** occurs for:

* Styles, fonts, images, animations
* Gradients and other visual components
* Components and globals registered in `globals.xml`

**Manual binding** is required for:

* Event callbacks (only available in code)
* Custom fonts or images stored in memory

To register name-data pairs, see the [Editor Integration](/integration) guide.

Arrays [#arrays]

Arrays can be defined in three ways:

| Syntax | Description |
| --- | --- |
| `int[5]` | Array with a fixed set of elements. |
| `string[NULL]` | Array terminated with a `NULL` element. `NULL` can be any other string too, for example `grid_dsc[LV_GRID_TEMPLATE_LAST]`. |
| `int[count]` | The number of elements is passed to the C API as a separate parameter. Used by `lv_chart`'s `values`, `lv_animimg`'s `src`, and `lv_line`'s `points`. |
| `string[]` | No termination or count parameter |

The termination of the array is important only to

1. Validate the correctness of the XML files
2. Generate correct code

The items in the array are separated by spaces and the termination is not included. For example

If there is an [`<api>`](./api) property like `<prop name="values" type="int[3]"/>` it can be used as `<my_widget values="10 33 55"/>`

String items need to be wrapped in `'` because an item can be composed of multiple words, so a space alone can't be used as a separator. For example `<prop name="list" type="string[NULL]"/>` it can be used as: `<my_widget values="'This is the first' 'The second' '3rd'"/>`

Enums [#enums]

Custom enums for **Widgets** can be created using `enumdef` (not supported for Components):

```xml title="xml" lineNumbers=1
<api>
  <enumdef name="my_widget_mode" help="Possible modes">
    <enum name="normal" value="0x10" help="Normal mode"/>
    <enum name="inverted" help="Inverted mode"/>
  </enumdef>

  <prop name="mode" type="enum:my_widget_mode" help="Select mode"/>
</api>
```

**Multiple enum values** with `+` suffix allow OR'ing values:

```xml title="xml" lineNumbers=1
type="axis+"  <!-- Allows selecting multiple axis values -->
axis="primary_x|secondary_y"  <!-- Separate with | -->
```

Compound Types [#compound-types]

Types can be combined to allow multiple options. For example:

```xml title="xml" lineNumbers=1
type="px|%|content"  <!-- Accepts pixels, percentage, or auto-size -->
```

Limiting Accepted Values [#limiting-accepted-values]

<Callout type="info">
  This feature is planned but not yet supported. The examples below show the intended syntax.
</Callout>

You can restrict possible values for enums, colors, and strings:

```xml title="xml" lineNumbers=1
<!-- Enum with limited options -->
type="dir(top bottom)"

<!-- Color with color palette -->
type="color(0xff0000 0x00ff00 0x0000ff)"

<!-- String with fixed options -->
type="string('Ok' 'Cancel')"
```

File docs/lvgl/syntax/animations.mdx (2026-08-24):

# Animations (/syntax/animations)

Create smooth, professional animations for your UI components using LVGL's timeline-based animation system, which allows you to define and control complex sequences with ease.

Overview [#overview]

XML animations are built on timeline animations that organize multiple animation steps into coordinated sequences.

Timelines are composed of simple animations. For example: &#x2A;"change the `bg_opa` of `my_button_2` from 0 to 255 in 500 ms."*

Each Component can define its own timeline animations, which can then be played by the Component itself or by any parent Components.

Defining Timelines [#defining-timelines]

Timelines can be defined inside [`<screen>`](./screens)s and [`<component>`](./components)s.

Example:

```xml title="xml" lineNumbers=1
<component>
 <animations>
  <!-- Show Component and its children -->
  <timeline name="load">
   <animation prop="translate_x" target="self" start="-30" end="0" duration="500"/>
   <animation prop="opa" target="text" start="0" end="255" duration="500" delay="200"/>
   <include_timeline target="icon" timeline="show_up" delay="300"/>
  </timeline>

  <!-- Shake horizontally -->
  <timeline name="shake" repeat_count="infinite" repeat_delay="200">
   <animation prop="translate_x" target="self" start="0" end="-30" duration="150"/>
   <animation prop="translate_x" target="self" start="-30" end="30" duration="300" delay="150"/>
   <animation prop="translate_x" target="self" start="30" end="0" duration="150" delay="450"/>
  </timeline>
 </animations>

 <view>
  <lv_button width="200">
   <my_icon name="icon" src="image1"/>
   <lv_label name="text" text="Click me"/>
  </lv_button>
 </view>
</component>
```

Timeline Properties [#timeline-properties]

Inside `<animations>`, you can define `<timeline>`s with unique names that you can reference later. A `<timeline>` supports these properties:

* `name` - Unique name used to reference and play the timeline.
* `repeat_count` - How many times the whole timeline repeats. Use a number, or `infinite` to loop forever. Default is `1`.
* `repeat_delay` - Delay in milliseconds between repetitions. Default is `0`.

Simple Animations [#simple-animations]

Within each `timeline`, add individual `<animation>` elements to describe each step. The following properties are supported:

* `prop` - Style property to animate. All integer, percentage, and color style properties are supported.
* `selector` - Style selector, e.g. `knob|pressed`. Default: `main|default`.
* `target` - Name of the UI element to animate. `self` refers to the root element of the Component (the `view`).
* `start` - Start value (integer only).
* `end` - End value (integer only).
* `duration` - Duration of the animation in milliseconds.
* `delay` - Delay before starting in milliseconds. Default is 0.
* `early_apply` - If `true`, the start value is applied immediately, even during the delay. Default is `false`.

Include External Timelines [#include-external-timelines]

The `include_timeline` element can be used in a `<timeline>` to reference animations from another timeline. For example, if `my_icon` defines a `"show_up"` timeline that fades in and enlarges the icon, you can include that timeline in other animations without duplicating the code.

To include a timeline, use the following properties:

* `target` - Name of the target UI element whose timeline should be included. `self` refers to the root element of the Component (the `view`).
* `timeline` - Name of the timeline to include. Must be defined in the `target`'s XML file.
* `delay` - Delay before starting in milliseconds. Default is 0.

Playing Timelines [#playing-timelines]

Timelines can be triggered by events (such as clicks) using the `<play_timeline_event>` element as a child of any widget.

Learn more about it in [Events](./events) section.

Under the Hood [#under-the-hood]

Understanding how timelines work internally helps you use them more effectively.

When an XML file is registered, the contents of the `animations` section are parsed, and the `timeline` data is stored as a "blueprint". The descriptors store target names as strings.

When a Component or Screen instance is created, `lv_anim_timeline`s are created and initialized from the saved blueprints. If `include_timeline`s are used, the requested timeline is included in the Component's timeline at this point. As all children are created at this point, the saved animation target names are resolved to pointers using `lv_obj_find_by_name`.

The created timeline instances and their names are saved in the Component's instance. Since each instance has its own timeline, you can have multiple Components (for example, 10 `list_item`s) and play their `load` timelines independently with different delays.

When a `play_timeline_event` is added to a UI element, the target and timeline names are saved as strings. Pointers cannot be used because the event can reference UI elements that will be created only later in the `view`.

Finally, when the play timeline event is triggered, the selected timeline is retrieved by its name from the target and started according to the other parameters (reverse, delay, and so on).

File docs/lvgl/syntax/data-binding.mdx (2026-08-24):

# Data Binding (/syntax/data-binding)

Overview [#overview]

With the help of subjects, the interface of the UI can be created.

A subject is a global data item whose value can be set either from the
application or the UI, and whose value can be bound to widget
properties.

<Callout type="info">
  Designing in Figma? You can bind layers to subjects directly in the plugin, no code required. See [Subjects & Data Binding in Figma Flow](../figma/subjects).
</Callout>

For example, a `room1_temperature` subject's value can be set in the
application when the temperature is measured, and can be bound to a
label like this:

```xml title="xml" lineNumbers=1
<lv_label bind_text="room1_temperature"/>
```

Defining subjects [#defining-subjects]

Subjects can be created in `globals.xml` like this:

```xml title="xml" lineNumbers=1
<globals>
  <subjects>
    <int name="battery_power" value="32"/>
    <string name="user_name" value="John"/>
    <float name="room_temperature" value="21.5"/>
  </subjects>
</globals>
```

As the example shows, a subject consists of a type, name, and initial
value. Integer, string, and float types are supported.

<Callout type="info">
  Float subjects require `LV_USE_FLOAT` to be enabled in `lv_conf.h`. Without it, the generated code fails to compile.
</Callout>

Simple binding [#simple-binding]

Some widgets (e.g., label, slider) support binding the subject's value
directly to the widget. These bindings use attributes that start with
`bind_*` and reference a subject.

```xml title="xml" lineNumbers=1
<lv_slider bind_value="some_subject"/>
<lv_label bind_text="some_subject"/>
```

Once a binding is created, if the subject's value changes (e.g., by
adjusting the slider), all bound widgets will be updated automatically.

Complex binding [#complex-binding]

In more complex cases---when a binding requires multiple
parameters---the binding can be added as a child element of a widget.
This allows binding multiple subjects with different parameters. For
example:

```xml title="xml" lineNumbers=1
<lv_label text="Hello world">
  <lv_obj-bind_flag_if_eq subject="subject1" flag="hidden" ref_value="10"/>
  <lv_obj-bind_flag_if_gt subject="subject1" flag="clickable" ref_value="20"/>
</lv_label>
```

Explanation of complex bindings:

| Binding Type | Condition | Description |
| --- | --- | --- |
| `bind_flag_if_eq` | Equals | Set a flag if the subject's value equals the reference value |
| `bind_flag_if_not_eq`  | Not equals | Set a flag if the subject's value does not equal the reference value |
| `bind_flag_if_gt` | Greater than | Set a flag if the subject's value is greater than the reference value |
| `bind_flag_if_ge` | Greater or equal | Set a flag if the subject's value is greater than or equal to the reference value  |
| `bind_flag_if_lt` | Less than | Set a flag if the subject's value is less than the reference value |
| `bind_flag_if_le` | Less or equal | Set a flag if the subject's value is less than or equal to the reference value |
| `bind_state_if_eq` | Equals | Set a state if the subject's value equals the reference value |
| `bind_state_if_not_eq` | Not equals | Set a state if the subject's value does not equal the reference value |
| `bind_state_if_gt` | Greater than | Set a state if the subject's value is greater than the reference value |
| `bind_state_if_ge` | Greater or equal | Set a state if the subject's value is greater than or equal to the reference value |
| `bind_state_if_lt` | Less than | Set a state if the subject's value is less than the reference value |
| `bind_state_if_le` | Less or equal | Set a state if the subject's value is less than or equal to the reference value |

Note: The `lv_obj-` prefix can be omitted. For example, you can simply
write `bind_state_if_gt` instead.

Choosing the right attribute [#choosing-the-right-attribute]

`bind_flag_*` and `bind_state_*` look almost identical but expect a different attribute and a different set of values:

* `bind_flag_*` toggles a widget **flag** — use the `flag` attribute.
* `bind_state_*` toggles a widget **state** — use the `state` attribute.

```xml title="xml" lineNumbers=1
<!-- Set the "hidden" flag while subject_mode != 1 -->
<lv_obj>
  <bind_flag_if_not_eq subject="subject_mode" flag="hidden" ref_value="1"/>
</lv_obj>

<!-- Enter the "checked" state while subject_lamp == 2 -->
<lv_obj>
  <bind_state_if_eq subject="subject_lamp" state="checked" ref_value="2"/>
</lv_obj>
```

Valid state values [#valid-state-values]

These match LVGL's `LV_STATE_*` constants. The same names are used as style selectors and in `bind_state_*` bindings.

| Value | Meaning |
| --- | --- |
| `default` | Widget is in its base state |
| `checked` | Widget is toggled on (e.g. a checkable button)  |
| `focused` | Widget has focus from any input device |
| `focus_key` | Widget has focus from a keypad/encoder |
| `edited` | Widget is being edited (e.g. encoder edit mode) |
| `hovered` | Pointer is over the widget |
| `pressed` | Widget is currently pressed |
| `scrolled`  | Widget is being scrolled |
| `disabled`  | Widget rejects input |

Valid flag values [#valid-flag-values]

The most commonly bound `LV_OBJ_FLAG_*` flags, exposed by the same names without the prefix:

| Value | Effect when set |
| --- | --- |
| `hidden` | Widget is not drawn and ignores input |
| `clickable` | Widget can be pressed/clicked |
| `checkable` | Click toggles the `checked` state |
| `scrollable` | Widget can be scrolled |
| `scroll_on_focus` | Parent scrolls so the focused child is visible |
| `floating` | Excluded from the parent's layout |
| `ignore_layout` | Ignored by the parent's layout |

For the full list of states and flags see LVGL's [Object basics](https://lvgl.io/docs/open/intro/basics) and [Style states](https://lvgl.io/docs/open/main-modules/style#states) reference.

Selection groups via a shared subject [#selection-groups-via-a-shared-subject]

A common pattern is to express "exactly one of these widgets is active" with a single integer subject and one `ref_value` per option. Combining `subject_set_int_event` (writes the subject on click) with `bind_state_if_eq` (reads it to drive the `checked` state) produces a runtime-driven radio group with no application code.

```xml title="xml" lineNumbers=1
<!-- globals.xml -->
<subjects>
  <int name="subject_lamp" value="0"/>
</subjects>
```

```xml title="xml" lineNumbers=1
<!-- lamp_cell.xml — one cell instantiated per option -->
<component>
  <api>
    <prop name="label" type="string" default="Lamp"/>
    <prop name="ref_value" type="int" default="0"/>
  </api>

  <view extends="lv_obj" width="content" height="content" flex_flow="column">
    <lv_label text="$label"/>

    <lv_button style_bg_color-checked="0xed7d31">
      <lv_image src="img_lightbulb"/>

      <!-- Read: this button is checked iff subject_lamp == ref_value -->
      <bind_state_if_eq subject="subject_lamp" state="checked" ref_value="$ref_value"/>

      <!-- Write: clicking this button stores ref_value in subject_lamp -->
      <subject_set_int_event subject="subject_lamp" trigger="clicked" value="$ref_value"/>
    </lv_button>
  </view>
</component>
```

```xml title="xml" lineNumbers=1
<!-- screen — each cell carries a unique ref_value -->
<lamp_cell label="Lamp 1" ref_value="0"/>
<lamp_cell label="Lamp 2" ref_value="1"/>
<lamp_cell label="Lamp 3" ref_value="2"/>
```

When the user taps a cell, `subject_lamp` is written to that cell's `ref_value`; every other cell's `bind_state_if_eq` re-evaluates and drops out of the `checked` state automatically. The same subject can also be set from C (`lv_subject_set_int(&subject_lamp, …)`) to drive the selection from application code.

Subject Related Events [#subject-related-events]

Besides binding properties to subjects, it's also possible to add
events that change the value of a subject on pressed, release, etc.

Learn more about these in the [events documentation](./events).

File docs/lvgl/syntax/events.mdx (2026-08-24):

# Events (/syntax/events)

Respond to user interactions by defining events on widgets that trigger callbacks, navigate between screens, or update application state when specific actions occur.

Overview [#overview]

There are several ways to define events for user interactions. These events can be added as children of any widget.

Triggers [#triggers]

In all event types, the `trigger` attribute defines what kind of user action should trigger the event. All LVGL event types are supported with straightforward mapping:

* `"all"` - `LV_EVENT_ALL`
* `"clicked"` - `LV_EVENT_CLICKED`
* `"pressed"` - `LV_EVENT_PRESSED`
* etc

Call Function [#call-function]

User-defined functions can be called in response to events like this:

```xml title="xml" lineNumbers=1
<view>
 <lv_button width="200" height="100">
  <event_cb callback="my_callback_1" trigger="clicked" user_data="some_text"/>
  <lv_label text="Hello"/>
 </lv_button>
</view>
```

The callback must follow the standard LVGL event callback signature:

```c title=" " lineNumbers=1
void an_event_handler(lv_event_t * e);
```

In exported C code, a function with the exact name is assumed to defined by the user.
For example, `callback="my_callback_1"` will be exported as:

```c title=" " lineNumbers=1
void my_callback_1(lv_event_t * e); /* At the beginning of the exported file */

lv_obj_add_event_cb(obj, my_callback_1, LV_EVENT_CLICKED, "some_text");
```

And it's the developer's responsibility to implement the `my_callback_1`.

Recommendations [#recommendations]

It's a good idea to add event function in the `<project_name>.c` file, created by the editor to keep all the related functions in one place. If there are a lot of event functions it's recommended to create multiple files for them.

To distinguish simulator builds from builds for an embedded device add defines like
`#define BUILD_SIMULATOR` and wrap the event callbacks to `#if BUILD_SIMULATOR`.

The `user_data` attribute is optional. If omitted, `NULL` will be passed.

Screen Load and Create Events [#screen-load-and-create-events]

Use the `screen_load_event` and `screen_create_event` tags as children of a widget or component to load or create screens in response to user interactions (such as a click).

The key difference between load and create is:

* **load** - Loads an already existing screen. After leaving the screen, it remains in memory, so all states are preserved. The screen to load must have [`<screen permanent="true"/>`](./screens)
* **create** - Creates the screen dynamically, and when leaving the screen, it is deleted, so all changes are lost (unless saved in subjects).   The screen to load must have [`<screen permanent="false"/>`](./screens) (`false` is the default).

Both tags support these optional attributes:

* `trigger` - Event code that triggers the action (e.g., `"clicked"`, `"long_pressed"`). Default: `"clicked"`.
* `anim_type` - How the screen is loaded (e.g., `"move_right"`, `"fade_in"`). Default: `"none"`.
* `duration` - Length of the animation in milliseconds. Default: `0`. Only used if `anim_type` is not `"none"`.
* `delay` - Wait time before loading the screen in milliseconds. Default: `0`.

Here is an example of both load and create events:

```xml title="xml" lineNumbers=1
<!-- screen1.xml -->
<screen permanent="true">
 <view style_bg_color="0xff7788">
  <lv_button>
   <lv_label text="Create"/>
   <!-- Create an instance of "screen2" and load it. -->
   <screen_create_event screen="screen2" anim_type="over_right" duration="500" delay="1000"/>
  </lv_button>
 </view>
</screen>

<!-- screen2.xml -->
<screen>
 <view style_bg_color="0x77ff88">
  <lv_button>
   <lv_label text="Load"/>
   <!-- Load an already created instance of screen1. -->
   <screen_load_event screen="screen1"/>
  </lv_button>
 </view>
</screen>
```

Set Subject Value [#set-subject-value]

You can set subject values in response to user interactions by adding special event tags as children of any widget:

```xml title="xml" lineNumbers=1
<view>
 <lv_button width="200" height="100">
  <subject_set_int_event trigger="clicked" subject="subject_int" value="10"/>
  <subject_set_float_event trigger="clicked" subject="subject_float" value="12.34"/>
  <subject_set_string_event trigger="clicked" subject="subject_string" value="Hello"/>
  <lv_label text="Set the values"/>
 </lv_button>
</view>
```

The specified `subject` will be set to the given `value` when the `trigger` event occurs.

Increment Subject Value [#increment-subject-value]

Increment or decrement subject values in response to events using the `subject_increment_event` element:

```xml title="xml" lineNumbers=1
<view>
 <lv_button width="200" height="100">
  <subject_increment_event trigger="clicked" subject="subject_int1" step="10"/>
  <subject_increment_event trigger="clicked" subject="subject_int2" step="-10" min_value="0" max_value="50"/>
  <subject_increment_event trigger="clicked" subject="subject_float1" step="2"/>
 </lv_button>
</view>
```

The `subject_increment_event` element adds a `step` value to the subject's current value when the `trigger` event occurs.

The `subject` must be an `int` or `float` type.

If `step` is negative, the subject's value will be decremented. Currently, only integer `step` values are supported.

Optionally, use `min_value` and/or `max_value` to limit the subject's value. The default min/max values are `INT32_MIN` (-2,147,483,648) and `INT32_MAX` (+2,147,483,647) respectively.

The `rollover` property is optional. If `false` (default), the value stops at the min/max boundary; if `true`, it wraps to the other end.

Play Animation [#play-animation]

Playing [Timelines](./animations) can be triggered by events (such as clicks) using the `<play_timeline_event>` element as a child of any widget.

Specify a `target` UI element and select one of its `timeline`s to play. If `target="self"`, the timeline is looked up in the current Component, or Screen (in the current XML file).

This example defines a timeline, and plays it on itself.

```xml title="xml" lineNumbers=1
<component>
	<animations>
		<timeline name="timeline_1">
			<animation target="self" duration="1000" prop="translate_x" start="100" end="0" />
			<animation target="main_button" duration="1000" prop="opa" start="0" end="255" />
		</timeline>
	</animations>

	<view>
		<lv_button name="main_button">
			<play_timeline_event trigger="clicked" timeline="timeline_1" target="self" />
			<lv_label text="Play" />
		</lv_button>
	</view>
</component>
```

Optionally a `delay` property can be set as well (in milliseconds), and the timeline can be played in reversed too:

```xml title="xml" lineNumbers=1
<play_timeline_event trigger="clicked" timeline="timeline_1" target="self" reverse="true" delay="500"/>
```

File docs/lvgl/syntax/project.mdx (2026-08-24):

# Project File (/syntax/project)

`project.xml` is the top-level configuration file of an LVGL Pro project. It is read by the Editor, by the CLI, and by the runtime XML loader to learn the target LVGL version, the exported code's name, and the display configurations used to render screens in the preview.

`project.xml` lives next to `globals.xml` at the root of the project folder.

Recommended Project Layout [#recommended-project-layout]

LVGL Pro doesn't enforce a folder structure, but the Editor, the tutorials, and the example projects all follow the same convention. Sticking to it keeps `src_path` references short and makes generated code predictable.

```
my_project/
├── project.xml          ← target/display configuration (this file)
├── globals.xml          ← shared fonts, images, subjects, consts, styles
├── translations.xml     ← optional, multi-language strings
├── fonts/               ← .ttf / .bin source files referenced by globals.xml
├── images/              ← .png assets referenced by globals.xml
├── widgets/             ← custom <widget> XMLs (one file per widget)
├── components/          ← reusable <component> XMLs (one file per component)
└── screens/             ← <screen> XMLs (one file per screen)
```

The three XML files (`project.xml`, `globals.xml`, `translations.xml`) sit at the project root; the five sub-folders hold everything else. Any of the sub-folders can be omitted if the project doesn't use that category.

Minimal Example [#minimal-example]

The simplest valid project file declares a `name`, the LVGL version, and at least one `<target>` with a `<display>`:

```xml title="xml" lineNumbers=1
<project name="ui" lvgl_version="9.5.0">
    <targets>
        <target name="target1">
            <display width="800" height="480"/>
        </target>
    </targets>    
</project>
```

This is enough for the Editor to load the project with a given resolution. However, `project.xml`
supports a whole lot of useful features. Keep reading to learn them all.

Multiple Targets [#multiple-targets]

To preview Screens at multiple resolutions of real hardware, declare multiple `<target>` elements inside `<targets>`.
Each target contains a `<display>` describing the screen size.

```xml title="xml" lineNumbers=1
<project name="ui" lvgl_version="9.5.0">
    <targets>
        <target name="large">
            <display width="800" height="480"/>
        </target>
        <target name="small">
            <display width="480" height="320"/>
        </target>
    </targets>
</project>
```

When a Screen is open in the Editor, the Preview panel shows one entry per `<target>`.
This is also how the Editor knows how to size a Screen's `<view>`.

It's also possible to conditionally use assets, styles or even views based on selected target.
It's a great way to manage assets and the appearance of components separately for different targets.
Learn more at [Targets](./targets)

Theme [#theme]
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

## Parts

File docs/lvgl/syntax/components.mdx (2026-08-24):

# Components (/syntax/components)

Components are powerful XML-based building blocks that let you create reusable, modular UI elements without writing C code.

Overview [#overview]

Components are one of the main building blocks for creating new UI elements. They are wrapped into a `<component>` root element and can have the following child XML tags:

* [`animations`](./animations) - Define timeline based animations
* [`consts`](./constants) - Local constants
* [`api`](./api) - Custom properties and slots (without `<enumdef>`s)
* [`styles`](./styles) - Local styles
* [`view`](./view) - Component structure
* [`previews`](./preview) - Preview configurations

Although components cannot contain C code, they are very powerful:

* They can extend another Component or Widget (that is the base can be defined)
* Components can be built from Widgets and other Components
* A custom [API](./api) can be defined
* Local [styles](./styles) can be defined, and global styles can be used
* Local [constants](./constants) can be defined, and global constants can be used
* Function calls, subject (variable) changes, or screen load/create events can be added
* Previews can be defined to preview components in various settings in the UI Editor

Extending Components and Widgets [#extending-components-and-widgets]

When a Component is created, it can extend another Component or Widget like [`<view extends="lv_slider">`](./view). If a Widget is extended, the component can use the Widget's API, for example:

```xml title="xml" lineNumbers=1
<component>
  <view extends="lv_slider" min_value="20"/>
</component>
```

If a Component is extended, the `api` properties can be used:

```xml title="xml" lineNumbers=1
<view extends="my_button" button_text="Apply">
```

Runtime vs. Code Generation [#runtime-vs-code-generation]

Unlike Widgets (which are always compiled into the application), Components can either:

1. Be exported to C code by the Editor and compiled with the application, or
2. Be loaded at runtime from XML

Using Components in XML [#using-components-in-xml]

Basic XML Usage [#basic-xml-usage]

Using Components in XML is very intuitive. The name of the Component can be used as an XML tag in the [`view`](./view) of other Components, [Screens](./screens), and [Widgets](./widgets). Component properties are simply XML attributes.

```xml title="xml" lineNumbers=1
<!-- my_button.xml -->
<component>
  <view extends="lv_button" flex_flow="row">
    <lv_image src="logo"/>
    <my_h3 text="Hello world"/>
  </view>
</component>
```

Exporting Components to Code [#exporting-components-to-code]

If loading XML at runtime is not needed, the [Editor](../editor/overview) or the [CLI](../cli) can export C and H files from the XML files of the Components. The resulting code is completely self-sufficient and **the XML files are not needed anymore**. The resulting code is similar to what you could write manually.

The exported code looks like this:

```c title=" " lineNumbers=1
lv_obj_t * component_name_create(lv_obj_t * parent, ...api properties...);
```

where `component_name` is the name of the  Component's XML file name.

When a Component is used in another Component's XML code and the code is exported, this `create` function will be called. This means Components do not have a detailed set/get API but are created with a fixed set of parameters.

If you need to access or modify values dynamically, it is recommended to use [data bindings via Subject](./data-binding). You can also call these `..._create()` functions at any time from application code to create new Components on demand.

Defining Custom Properties [#defining-custom-properties]

The properties of child elements can be adjusted directly:

```xml title="xml" lineNumbers=1
<my_button x="10" width="200"/>
```

However, you can also define custom properties in the [`api` tag](./api). These properties can then be passed to any properties of the children by referencing them using `$`. For example:

```xml title="xml" lineNumbers=1
<!-- my_button.xml -->
<component>
  <api>
    <prop name="btn_text" type="string"/>
  </api>

  <view extends="lv_button">
    <lv_label text="$btn_text"/>
  </view>
</component>
```

And it can be used like:

```xml title="xml" lineNumbers=1
<!-- my_list.xml -->
<component>
  <view>
    <my_button btn_text="First"/>
    <my_button btn_text="Second"/>
    <my_button btn_text="Third"/>
  </view>
</component>
```

Optional properties [#optional-properties]

In this setup, the `btn_text` property is mandatory. However, you can make it optional by setting a default value:

```xml title="xml" lineNumbers=1
<prop name="btn_text" type="string" default="Title"/>
```

See the [API documentation](./api) for more details and XML syntax reference for all the supported types.

Complete Examples [#complete-examples]

The following examples demonstrate parameter passing, styles, and constants in Components.

Simple Component [#simple-component]

```xml title="xml" lineNumbers=1
<!-- h3.xml -->
<component>
  <view extends="lv_label" style_text_color="0xffff00"/>
</component>
```

Advanced Component with Styles and Constants [#advanced-component-with-styles-and-constants]

```xml title="xml" lineNumbers=1
<!-- red_button.xml -->
<component>
  <api>
    <prop type="string" name="btn_text" default="None"/>
  </api>

  <consts>
    <int name="thin" value="2"/>
  </consts>

  <styles>
    <style name="pressed_style" border_width="#thin" border_color="0xff0000"/>
  </styles>

  <view extends="lv_button" style_radius="0" style_bg_color="0xff0000">
    <style name="pressed_style" selector="pressed"/>
    <h3 text="Some text"/>
    <h3 text="$btn_text" y="40"/>
  </view>
</component>
```

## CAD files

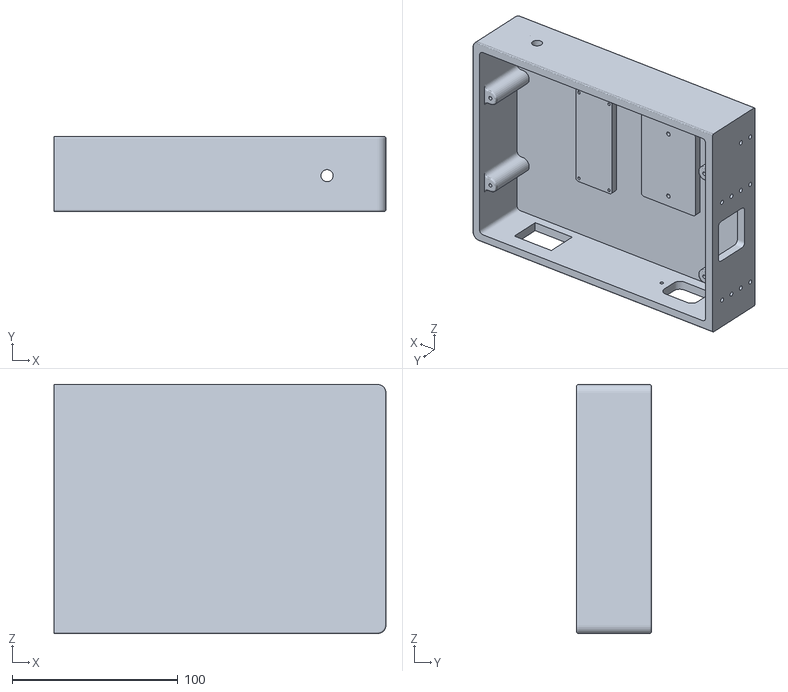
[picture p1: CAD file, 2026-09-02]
assets/3d files/Frame - Main.stl
200.0 x 45.0 x 150.0

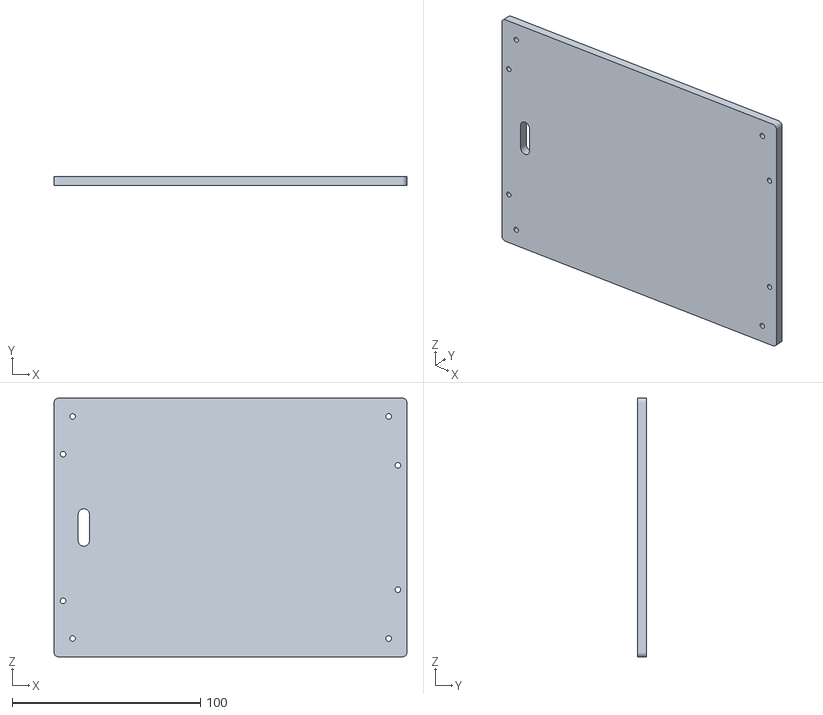
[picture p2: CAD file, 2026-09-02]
assets/3d files/Top Plate.stl
187.6 x 4.90 x 137.6

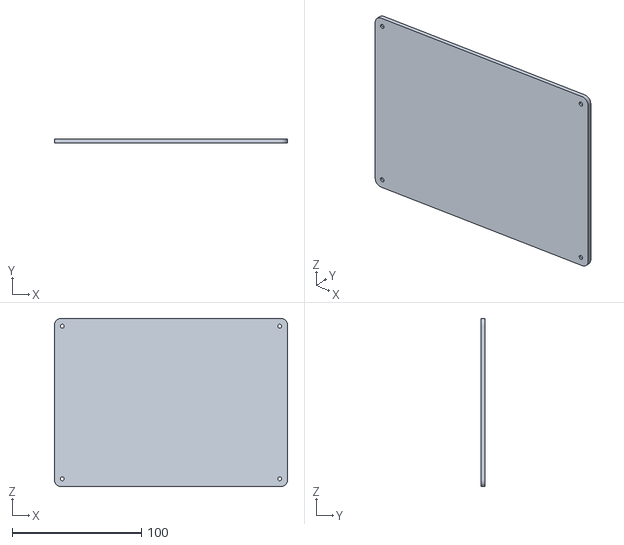
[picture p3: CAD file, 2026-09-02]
assets/3d files/Heating Plate.stl
180.0 x 3.00 x 130.0

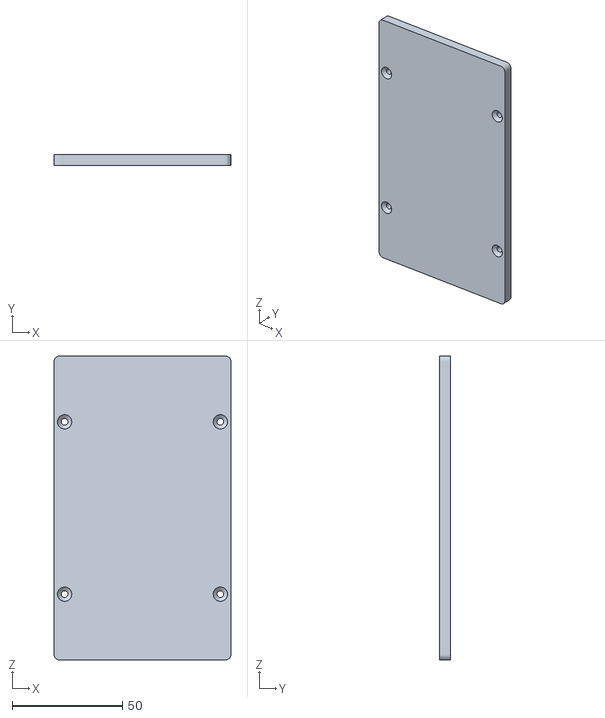
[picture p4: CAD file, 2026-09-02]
assets/3d files/Display Bottom Plate.stl
80.1 x 5.00 x 137.6

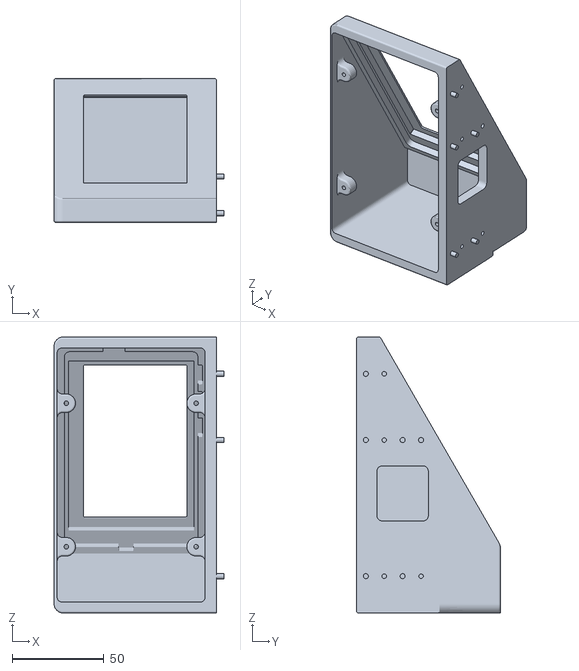
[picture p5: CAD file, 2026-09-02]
assets/3d files/Frame - Display.stl
92.4 x 78.1 x 150.0

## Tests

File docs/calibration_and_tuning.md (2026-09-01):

# Calibration & Controller Tuning Guide

This guide details how to verify sensor calibration, tune the PI temperature regulation parameters, calibrate thermal runaway limits, and customize reflow soldering profiles in **Tejasvini**.

---

## 1. NTC Thermistor Calibration

Accurate temperature reading depends on knowing the exact resistance of the voltage divider resistors and the nominal thermistor parameters.

### 1.1 Voltage Divider Resistor Calibration
While nominal 100kΩ resistors are specified, standard 1% resistors can vary between 99.0kΩ and 101.0kΩ, resulting in a 1°C to 2°C temperature offset.

**To calibrate:**
1. Power off the system and disconnect the thermistor plug.
2. Measure the actual resistance between the ADC pin (GPIO 26 or GPIO 27) and GND using a calibrated 4.5-digit or 5.5-digit Digital Multimeter (DMM).
3. If your measured resistance is e.g. $99{,}400\,\Omega$, update `R_DIVIDER` in [`src/config.h`](file:///Users/jrsarath/Documents/GitHub/Tejasvini/src/config.h):
   ```c
   #define R_DIVIDER 99400.0f // Measured divider resistance in Ohms
   ```

### 1.2 Verifying Sensor Readings at Ambient
1. Connect both thermistors and boot the firmware.
2. Open the serial terminal at 115200 baud. The boot banner and initial reading will log:
   ```text
   [Thermal] Initialized: NTC1=24.8C (2048 ADC, 100120R), NTC2=25.0C (2046 ADC, 99950R)
   ```
3. Verify that both readings match the room ambient temperature measured by a reference thermometer within $\pm 1.0^\circ\text{C}$.

---

## 2. PI Controller Tuning

Tejasvini utilizes a proportional-integral (PI) regulator with soft-start reference ramping. The controller constants are defined in `src/config.h`:

```c
#define KP_GAIN 1.5f  // Proportional gain
#define KI_GAIN 0.02f // Integral gain
```

### 2.1 Understanding Controller Parameters
* **`RAMP_RATE_DEG_PER_SEC` ($1.5^\circ\text{C}/\text{s}$)**: Soft-start ramp speed. The setpoint gradually climbs toward the target rather than stepping instantly, preventing overshoot and thermal shock.
* **`KP_GAIN` ($1.5$)**: Reacts immediately to temperature error.
  * *Too high:* The plate will oscillate around the target temperature by $\pm 3^\circ\text{C}$ to $5^\circ\text{C}$.
  * *Too low:* The plate will respond sluggishly and take too long to reach the target.
* **`KI_GAIN` ($0.02$)**: Gradually eliminates steady-state droop caused by ambient cooling losses.
  * *Too high:* Causes phase lag, overshoot at the end of the ramp, and slow hunting oscillations.
  * *Too low:* Plate may settle 1°C to 2°C below the target temperature indefinitely.

### 2.2 Tuning Procedure for Custom Plates
If using a heavier aluminum plate (e.g. 100mm $\times$ 100mm $\times$ 10mm thick), the thermal mass is significantly greater:
1. Start with `KP_GAIN = 1.0` and `KI_GAIN = 0.01`.
2. Heat the plate to 150°C and observe the steady-state graph on the serial telemetry monitor.
3. If temperature settles below 150°C, increase `KI_GAIN` by `0.005` increments until zero steady-state error is achieved.
4. If temperature oscillates continually, decrease `KP_GAIN` by `0.2` increments.

---

## 3. Thermal Runaway Tuning

The thermal runaway monitor protects against detached thermistors or failing SSRs:

```c
#define SAFETY_PERIOD 18000 // Check window in milliseconds (18 seconds)
#define SAFETY_THRESHOLD 2.0f // Minimum required temperature rise (°C)
```

### Tuning Considerations:
* When driving $\ge 20\%$ duty with a deficit $> 10^\circ\text{C}$, temperature must rise by at least `2.0°C` every `18` seconds.
* If you operate an unusually heavy, uninsulated heatplate or operate in cold ambient environments ($< 10^\circ\text{C}$), the rise rate near 200°C might slow down.
* If a false thermal runaway trip occurs on a very heavy plate, increase `SAFETY_PERIOD` to `25000` (25 seconds). Never disable the check entirely.

---

## 4. Customizing Reflow Soldering Profiles

Reflow profile parameters reside in `src/display_manager.cpp` in `g_profile_configs`:

```cpp
struct ProfileStageConfig {
  int preheat_temp;        // °C (preheat target)
  uint32_t preheat_time_s; // target duration in preheat (seconds)
  int soak_temp;           // °C (soak target)
  uint32_t soak_time_s;    // seconds in soak zone
  int peak_temp;           // °C (peak reflow target)
  uint32_t peak_dwell_s;   // seconds dwell at peak
  int cool_temp;           // °C (safe handling temperature)
  uint32_t cool_time_s;    // nominal cooling duration (seconds)
};
```

### Preconfigured Profiles:
1. **Lead-Free (SAC305 / Sn96.5Ag3.0Cu0.5)**:
   - Preheat: 150°C (90s)
   - Soak: 175°C (60s)
   - Peak: 245°C (30s dwell)
   - Cool: 50°C
2. **Leaded (Sn63Pb37)**:
   - Preheat: 130°C (80s)
   - Soak: 155°C (60s)
   - Peak: 215°C (30s dwell)
   - Cool: 50°C
3. **Low-Temperature (Sn42Bi58 Bismuth)**:
   - Preheat: 90°C (60s)
   - Soak: 115°C (45s)
   - Peak: 150°C (25s dwell)
   - Cool: 45°C

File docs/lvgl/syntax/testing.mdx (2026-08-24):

# Testing (/syntax/testing)

Overview [#overview]

Write comprehensive UI tests using XML to verify functionality and visual consistency of your LVGL interfaces.

The XML test module is a powerful and flexible way to define functional UI tests.

Test XML files are similar to components but are wrapped in a `<test>`
tag and consist of two main parts:

* **UI Definition**: Use [`<styles>`](./styles), [`<consts>`](./constants), and [`<view>`](./view) to define
  how the UI should look. This is identical to how [`<component>`](./components)s are
  structured.
* **Test Steps**: Encapsulated in a `<steps>` tag, these define the
  actions and assertions for the test.

Step Types [#step-types]

The following step types are currently supported:

| Step | Parameters | Description |
| --- | --- | --- |
| `<move_to x="10" y="30"/>` | `x`, `y` | Move the mouse to the specified screen coordinates |
| `<click_at x="10" y="30"/>` | `x`, `y` | Simulates a click at the specified screen coordinates |
| `<press/>` | — | Press on the current screen coordinate |
| `<release/>` | — | Release on the current screen coordinate |
| `<wait ms="100"/>` | `ms` | Waits for the given number of milliseconds. LVGL continues running, including animations and timers |
| `<freeze ms="100"/>` | `ms` | Pauses the UI and LVGL's internal time. Useful for visual debugging |
| `<subject_set subject="subject1" value="5"/>` | `subject`, `value` | Set an integer or string subject's value |
| `<subject_compare subject="subject1" value="10"/>` | `subject`, `value` | Compare an integer or string subject's value against a reference value |
| `<screenshot_compare path="path/to/image.png"/>` | `path` | Compares the current screen with a reference image. If the image doesn't exist, it is created. If the comparison fails, an image with `_err` suffix is saved for inspection |

Example:

```xml title="xml" lineNumbers=1
<test width="300" height="400">
 <view width="100%" height="100%" flex_flow="column">
 <lv_checkbox text="First one!"/>
 <lv_slider />
 </view>

 <steps>
   <screenshot_compare path="imgs/before.png"/>
   <click_at x="32" y="32"/>
   <subject_compare subject="subject2" value="50"/>
   <click_at x="50" y="64"/>
   <subject_set subject="subject2" value="10"/>
   <wait ms="300"/>
   <screenshot_compare path="imgs/after.png"/>
 </steps>
</test>
```

Running Tests [#running-tests]

Use the "Test" panel of the Editor to see and run tests, or run them with the CLI in a CI/CD pipeline.

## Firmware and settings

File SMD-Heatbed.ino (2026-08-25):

/*******************************************************************************
 * SMD Heatbed Firmware
 * Open-Source Heatplate Controller for SMT Reflow Soldering
 *
 * Board:   Raspberry Pi Pico (RP2040)
 * Display: Elecrow 4.3" Pico DVI Display (320x240)
 * Sensor:  100K NTC Thermistor (ADC2, GPIO 28)
 * Output:  3.3V Logic Solid State Relay PWM (GPIO 22)
 * Input:   Rotary Encoder with Push-Button & Touchscreen (GT911)
 ******************************************************************************/

#include "src/config.h"
#include "src/display_manager.h"
#include "src/input_handler.h"
#include "src/telemetry.h"
#include "src/thermal_control.h"
#include "src/touch.h"
#include <lvgl.h>

// Hardware Timers
static RPI_PICO_Timer TimerRegulator(0);
static RPI_PICO_Timer TimerAcquisition(1);

/**
 * @brief Main setup function
 */
void setup() {
  // 1. Initialize Telemetry UART (Serial1 @ 115200 baud)
  telemetry_init();

  // 2. Initialize Thermal Control & Input (Commented out for isolation)
  // thermal_control_init();
  // input_init();

  // 3. Initialize PicoDVI Display & Touch Subsystems
  touch_init();
  display_manager_init();

  // 4. Attach Hardware Timer ISR Handlers (Temporarily commented for stack
  // collision testing)
  /*
  if (!TimerRegulator.attachInterruptInterval(2000, regulator_isr)) {
    Serial1.println("ERROR: Failed to attach Regulator Timer ISR!");
  }

  if (!TimerAcquisition.attachInterruptInterval(200, acquisition_isr)) {
    Serial1.println("ERROR: Failed to attach Acquisition Timer ISR!");
  }
  */

  Serial1.println("Setup completed successfully.");
}

/**
 * @brief Main execution loop
 */
void loop() {
  // Update DVI Display Dashboard & LVGL UI tasks
  display_manager_update();

  // Log Telemetry Data to Serial Output
  telemetry_update();

  delay(5);
}

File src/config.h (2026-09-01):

#ifndef CONFIG_H_
#define CONFIG_H_

#include <Arduino.h>

/*******************************************************************************
 * Firmware Metadata
 ******************************************************************************/
#define FIRMWARE_NAME "Tejasvini"
#define FIRMWARE_VERSION "v1.0.1"
#define FIRMWARE_AUTHOR "Sarath \"Delta\" Singh"
#define FIRMWARE_GITHUB "https://github.com/jrsarath/Tejasvini"

/*******************************************************************************
 * Hardware Pinout Configuration
 ******************************************************************************/
#define PIN_ENA 2        // Rotary Encoder Phase A (GPIO 2)
#define PIN_ENB 3        // Rotary Encoder Phase B (GPIO 3)
#define PIN_EBT 28       // Rotary Encoder Push-Button (GPIO 28)
#define PIN_SSR 22       // Solid State Relay PWM Output (GPIO 22)
#define PIN_NTC1 26      // Primary NTC Thermistor ADC Input (ADC0, GPIO 26)
#define PIN_NTC2 27      // Secondary NTC Thermistor ADC Input (ADC1, GPIO 27)
#define PIN_NTC PIN_NTC1 // Backward compatibility alias
#define PIN_BACKLIGHT 24 // Display Backlight Control (Active LOW, GPIO 24)

#define SERIAL_TX 0 // Telemetry UART TX (GPIO 0)
#define SERIAL_RX 1 // Telemetry UART RX (GPIO 1)
#define SERIAL_BAUD 115200

/*******************************************************************************
 * Display Specifications (Elecrow CrowPanel RTD2281 4.3" DVI Display)
 * Hardware DVI Resolution: 400x240 @ 60Hz (scaled 2x to 800x480 by RTD2281)
 * Logical UI Resolution: 240x400 (Portrait Mode, 270° hardware rotation)
 ******************************************************************************/
#define SCREEN_WIDTH 240  // Logical UI horizontal resolution (pixels, portrait)
#define SCREEN_HEIGHT 400 // Logical UI vertical resolution (pixels, portrait)
#define DISPLAY_WIDTH                                                          \
  400 // Hardware DVI horizontal resolution (pixels, landscape)
#define DISPLAY_HEIGHT                                                         \
  240 // Hardware DVI vertical resolution (pixels, landscape)
#define DISPLAY_ROTATION 3 // Display Rotation 90 * 3 = 270° (Portrait)

/*******************************************************************************
 * Temperature & Controller Parameters
 ******************************************************************************/
#define MIN_TEMP 0   // Minimum allowable setpoint (°C)
#define MAX_TEMP 270 // Maximum allowable setpoint (°C)
#define CONTROL_PERIOD_MS                                                      \
  100 // Thermal control loop update interval (ms, 10 Hz)
#define RAMP_RATE_DEG_PER_SEC                                                  \
  1.5f                 // Soft-start reference ramping rate (°C/second)
#define REF_STEP 0.05f // Backward compatibility alias

// Dual NTC Voltage Divider Specifications
#define R_DIVIDER 100000.0f // Series divider resistor value (100k Ohms)
#define R0_THERMISTOR                                                          \
  100000.0f                // Thermistor nominal resistance at T0 (100k Ohms)
#define BETA_COEFF 3950.0f // Thermistor Beta coefficient (K)
#define T0_KELVIN 298.15f  // Nominal reference temperature (25°C in Kelvin)

// Dual NTC Sensor Safety Bounds
#define NTC_MIN_VALID_TEMP                                                     \
  -20.0f // Minimum physically valid sensor reading (°C)
#define NTC_MAX_VALID_TEMP                                                     \
  300.0f // Maximum physically valid sensor reading (°C)
#define ADC_MIN_VALID_COUNTS                                                   \
  50 // Minimum plausible raw 12-bit ADC count (detects open circuit / GND short)
#define ADC_MAX_VALID_COUNTS                                                   \
  4050 // Maximum plausible raw 12-bit ADC count (detects 3.3V power short)
#define MAX_STARTUP_NTC_DIFF                                                   \
  15.0f // Max allowable temp delta between NTCs before heating can start (°C)
#define MAX_NTC_DIFF                                                           \
  35.0f // Max allowable temp delta between NTCs during heating (°C)
#define OVERTEMP_SHUTDOWN                                                      \
  280.0f // Absolute emergency thermal shutdown limit (°C)

// PI Controller Constants (Calibrated for seconds-based delta-time integration)
#define KP_GAIN 1.5f  // Proportional gain
#define KI_GAIN 0.02f // Integral gain
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

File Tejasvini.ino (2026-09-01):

/*******************************************************************************
 * Tejasvini Firmware
 * Open-Source Heatplate Controller for SMT Reflow Soldering
 *
 * Board:   Raspberry Pi Pico (RP2040)
 * Display: Elecrow CrowPanel RTD2281 4.3" Pico DVI Display (400x240 / 800x480 Scaled)
 * Sensors: Dual 100K NTC Thermistors (NTC1: ADC0/GPIO 26, NTC2: ADC1/GPIO 27)
 * Output:  Solid State Relay (GPIO 22, AC Zero-Cross Time Proportioning / PWM)
 * Input:   Rotary Encoder (GPIO 2, 3, 28) & Capacitive Touchscreen (GT911)
 * Telemetry: Serial (USB CDC) & Serial1 (GPIO 0 TX, GPIO 1 RX) @ 115200 baud
 ******************************************************************************/

#include "src/config.h"
#include "src/display_manager.h"
#include "src/input_handler.h"
#include "src/telemetry.h"
#include "src/thermal_control.h"
#include "src/touch.h"
#include <lvgl.h>

void setup() {
  // 1. Initialize Telemetry UART (Serial1 @ 115200 baud & USB CDC)
  telemetry_init();

  // 2. Initialize Thermal Control & Input Subsystems
  thermal_control_init();
  input_init();

  // 3. Initialize PicoDVI Display & Touch Subsystems
  touch_init();
  display_manager_init();

  log_println("[System] Setup completed successfully. Entering main execution loop.");
}

/**
 * @brief Main execution loop (cooperative, non-blocking scheduling)
 */
void loop() {
  // 1. Poll inputs (rotary encoder quadrature decoding & debounced button)
  input_handler_update();

  // 2. Regulate heatplate thermal control & update SSR actuation
  thermal_control_update();

  // 3. Update DVI Display Dashboard & LVGL UI tasks
  display_manager_update();

  // 4. Log Telemetry Data to Serial Output
  telemetry_update();

  // Yield to allow background microcontroller housekeeping
  yield();
}

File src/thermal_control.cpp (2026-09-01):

#include "thermal_control.h"
#include "telemetry.h"
#include <math.h>

// Global hardware instances
#if !SSR_TIME_PROPORTIONING
static RP2040_PWM *pwm_ssr = nullptr;
#endif

// Internal state variables (volatile for thread/ISR safe access)
static volatile int set_temp = 0;
static volatile float reference_temp = 0.0f;
static volatile float measured_temp = 0.0f;  // Composite (average) temperature
static volatile float measured_temp1 = 0.0f; // NTC 1 temperature
static volatile float measured_temp2 = 0.0f; // NTC 2 temperature
static volatile float measured_resistance1 = 0.0f;
static volatile float measured_resistance2 = 0.0f;
static volatile int adc_raw1 = 0;
static volatile int adc_raw2 = 0;

static volatile float duty = 0.0f;
static volatile float acc = 0.0f;
static volatile float error = 0.0f;

static volatile bool heater = false;
static volatile uint32_t heater_turned_on = 0;

static volatile float last_safety_temp = 0.0f;
static volatile uint32_t last_safety_check = 0;
static volatile bool error_state = false;

static uint8_t divergence_fault_count = 0;
static uint32_t window_start_time = 0;
static uint32_t last_control_time = 0;
static bool first_sample = true;

/**
 * @brief Computes thermistor resistance and Steinhart-Hart/Beta temperature from raw ADC.
 */
static float calculate_ntc_temperature(int raw_adc, float &out_resistance) {
  // Clamp ADC input to valid non-zero, non-saturated range
  if (raw_adc <= 0) raw_adc = 1;
  if (raw_adc >= 4095) raw_adc = 4094;

  // Voltage divider resistance calculation (12-bit ADC full scale: 4095 counts)
  // NTC connected between 3.3V and ADC pin; R_DIVIDER connected between ADC pin and GND
  float resistance = R_DIVIDER * (4095.0f / (float)raw_adc - 1.0f);
  if (resistance <= 0.001f) resistance = 0.001f;
  out_resistance = resistance;

  // Standard Steinhart-Hart / Beta equation: 1/T = 1/T0 + (1/Beta) * ln(R / R0)
  float steinhart = (1.0f / T0_KELVIN) + (1.0f / BETA_COEFF) * logf(resistance / R0_THERMISTOR);
  float temp_c = (1.0f / steinhart) - 273.15f;

  return temp_c;
}

/**
 * @brief Immediately forces the heater OFF, zeroes PWM duty/integrator, and latches safety error state.
 */
void trigger_safety_shutdown(const char *reason) {
  error_state = true;
  heater = false;
  duty = 0.0f;
  acc = 0.0f;
  reference_temp = measured_temp;

#if SSR_TIME_PROPORTIONING
  digitalWrite(PIN_SSR, LOW);
#else
  if (pwm_ssr) {
    pwm_ssr->setPWM(PIN_SSR, (float)PWM_FREQUENCY, 0.0f);
  }
#endif

  if (reason) {
    log_printf("[Thermal] EMERGENCY SAFETY SHUTDOWN: %s", reason);
  }
}

/**
 * @brief Low-level SSR driver supporting both AC Time-Proportioning and Hardware PWM.
 */
static void update_ssr_actuation(uint32_t now) {
  if (error_state || !heater || duty <= MIN_DUTY) {
#if SSR_TIME_PROPORTIONING
    digitalWrite(PIN_SSR, LOW);
#else
    if (pwm_ssr) pwm_ssr->setPWM(PIN_SSR, PWM_FREQUENCY, 0.0f);
#endif
    return;
  }

#if SSR_TIME_PROPORTIONING
  if (now - window_start_time >= SSR_WINDOW_MS) {
    window_start_time = now;
  }
  uint32_t elapsed = now - window_start_time;
  uint32_t on_time = (uint32_t)((duty / 100.0f) * (float)SSR_WINDOW_MS);

  if (elapsed < on_time) {
    digitalWrite(PIN_SSR, HIGH);
  } else {
    digitalWrite(PIN_SSR, LOW);
  }
#else
  if (pwm_ssr) {
    pwm_ssr->setPWM(PIN_SSR, (float)PWM_FREQUENCY, duty);
  }
#endif
}

void thermal_control_init() {
  pinMode(PIN_SSR, OUTPUT);
  digitalWrite(PIN_SSR, LOW);
  pinMode(PIN_NTC1, INPUT);
  pinMode(PIN_NTC2, INPUT);
  analogReadResolution(12);

#if !SSR_TIME_PROPORTIONING
  // Initialize RP2040 PWM driver for SSR
  pwm_ssr = new RP2040_PWM(PIN_SSR, PWM_FREQUENCY, 0.0f);
  if (pwm_ssr) {
    pwm_ssr->setPWM();
  }
#endif

  // Initial sensor measurement so system starts with valid temperature
  first_sample = true;
  measure_temperature();
  reference_temp = measured_temp;
  window_start_time = millis();
  last_control_time = millis();

  if (error_state) {
    log_printf("[Thermal] WARNING: System booted into SAFETY ERROR state due to invalid initial sensor readings!");
  } else {
    log_printf("[Thermal] Initialized: NTC1=%.1fC (%d ADC, %.0fR), NTC2=%.1fC (%d ADC, %.0fR), SSR Mode=%s",
               measured_temp1, adc_raw1, measured_resistance1,
               measured_temp2, adc_raw2, measured_resistance2,
               SSR_TIME_PROPORTIONING ? "AC Time-Proportioning (1000ms window)" : "Hardware PWM (1000Hz)");
  }
}

/**
 * @brief Reads RP2040 ADC with 32x oversampling and trimmed-mean outlier rejection.
 * Eliminates high-frequency power rail ripple, DVI line noise, and random ADC glitch pulses.
 */
static int read_oversampled_adc(uint8_t pin) {
  // Discard first conversion after multiplexer switch to settle S&H capacitor
  (void)analogRead(pin);

  constexpr int TOTAL_SAMPLES = 32;
  constexpr int TRIM_EACH_SIDE = 6; // Discard 6 highest and 6 lowest outlier readings
  constexpr int KEPT_SAMPLES = TOTAL_SAMPLES - (TRIM_EACH_SIDE * 2); // 20 middle samples

  uint16_t samples[TOTAL_SAMPLES];
  for (int i = 0; i < TOTAL_SAMPLES; i++) {
    samples[i] = (uint16_t)analogRead(pin);
    delayMicroseconds(4);
  }

  // Fast insertion sort on small 32-element array
  for (int i = 1; i < TOTAL_SAMPLES; i++) {
    uint16_t key = samples[i];
    int j = i - 1;
    while (j >= 0 && samples[j] > key) {
      samples[j + 1] = samples[j];
      j--;
    }
    samples[j + 1] = key;
  }

  uint32_t sum = 0;
  for (int i = TRIM_EACH_SIDE; i < TOTAL_SAMPLES - TRIM_EACH_SIDE; i++) {
    sum += samples[i];
  }
  return (int)((sum + (KEPT_SAMPLES / 2)) / KEPT_SAMPLES);
}
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

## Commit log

2025-11-20 Refactors UI updates to main loop
    Moves UI updates from ISRs to the main loop to ensure thread safety and prevent potential crashes.
    Introduces flags to signal UI updates and corresponding state variables for temperature and status. Updates are performed only when necessary, reducing unnecessary LVGL calls.
2025-11-20 Refactors and initializes the LVGL UI
    Moves LVGL initialization to the setup function for better organization.
    Adds a splash screen timer to transition to the main UI after 5 seconds.
    Initializes the input device driver.
2025-12-03 Increases temperature adjustment increments
    Increases the temperature adjustment increments to 10
    degrees, providing a more significant change with each
    adjustment.
    Adds .DS_Store to .gitignore.
2026-08-26 ui prototype
2026-09-02 add models
    [Frame - Display.stl, Frame - Main.stl]
2026-09-02 3d files
    [Display Bottom Plate.stl, Heating Plate.stl, Top Plate.stl]
